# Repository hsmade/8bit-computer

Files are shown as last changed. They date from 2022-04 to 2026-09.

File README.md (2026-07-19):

# My 8-bit computer

This repo describes my homebrew 8-bit computer. 
It is loosely based on the works of  [Ben eater's 6502 computer](https://eater.net/6502), and others.

A build log can be found [here](https://hsmade.github.io/8bit-computer)

## Components
### CPU card
This card contains the CPU and the RAM.

To be built.

* more info [here](CPU/README.md)
* the schematics can be found [here](CPU/kicad/)

### ROM card
This card holds the rom, and exposes a pin header for programming.
I currently do the programming with an Arduino Mega (because I need a lot of IO ports).
The software for programming the eeprom can be found [here](ROM/programmer/README.md)

* more info [here](ROM/README.md).
* the schematic can be found [here](ROM/kicad/).

### Bus display card
This card shows the current contents of the address and data bus, and if the CPU is reading or writing.
I used the trick to alternate between 2 displays, using a timer, from Ben Eater.
This doesn't use the whole flip-flop setup though, as I use just 2 displays per 8 bits (hex).

* more info [here](bus-display/README.md)
* the schematic can be found [here](bus-display/kicad/).

### IO card
This card will interface with the outside world.
The idea is to control a 1602A display, and a serial port.

To be designed and built.

## Requirements
The following software is required to run makefiles:
* cc65
* platformio

## Memory map
http://wilsonminesco.com/6502primer/addr_decoding.html
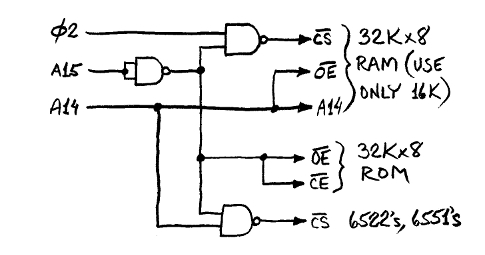
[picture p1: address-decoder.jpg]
address decoder


| start | end  | what | A15 | A14 | A13 | A12 | A11 | A10 | A9 | A8 | A3 | A2 |
|---|---|---|-----|-----|-----|-----|-----|-----|----|----|----|----|
| 0000  | 3FFF | RAM | 0 | 0 | x | x | x | x |  x |  x |  x |  x |
| 4100  | | ACIA 3-1 | 0 | 1 | 0 | 0 | 0 | 0 |  0 |  1 |  0 |  0 |
| 4104  | | ACIA 3-2 | 0 | 1 | 0 | 0 | 0 | 0 |  0 |  1 |  0 |  1 |
| 4108  | | ACIA 3-3 | 0 | 1 | 0 | 0 | 0 | 0 |  0 |  1 |  1 |  0 |
| 410C  | | ACIA 3-4 | 0 | 1 | 0 | 0 | 0 | 0 |  0 |  1 |  1 |  1 |
| 4200  | | ACIA 2-1 | 0 | 1 | 0 | 0 | 0 | 0 |  1 |  0 |  0 |  0 |
| 4204  | | ACIA 2-2 | 0 | 1 | 0 | 0 | 0 | 0 |  1 |  0 |  0 |  1 |
| 4208  | | ACIA 2-3 | 0 | 1 | 0 | 0 | 0 | 0 |  1 |  0 |  1 |  0 |
| 420C  | | ACIA 2-4 | 0 | 1 | 0 | 0 | 0 | 0 |  1 |  0 |  1 |  1 |
| 4400  | 4403 | ACIA 1 | 0 | 1 | 0 | 0 | 0 | 1 |  0 |  0 |  0 |  0 |
| 4800  | 480F | VIA 3 | 0 | 1 | 0 | 0 | 1 | 0 |  0 |  0 |  x |  x |
| 5000  | 500F | VIA 2 | 0 | 1 | 0 | 1 | 0 | 0 |  0 |  0 |  x |  x |
| 6000  | 600F | VIA 1 | 0 | 1 | 1 | 0 | 0 | 0 |  0 |  0 |  x |  x |
| 8000  | FFFF | ROM | 1 | x | x | x | x | x |  x |  x |  x |  x |

`A1` and `A0` select registers inside each ACIA. `A3` through `A0`
select registers inside each VIA. `A7` through `A4` are not decoded in
this memory map.

## Bus

| Use | Port | Port | Use |
|-----|---|---|---|
| VSS | 1 | 40 | VSS |
| X | 2 | 39 | Phi 0 |
| X | 3 | 38 | X |
| +5V | 4 | 37 | +5V |
| A0  | 5 | 36 | X |
| A1  | 6 | 35 | CSb |
| A2  | 7 | 34 | RES |
| A3  | 8 | 33 | NMI |
| A4  | 9 | 32 | IRQ |
| A5  | 10 | 31 | Phi 1 |
| A6  | 11 | 30 | Phi 2 |
| A7  | 12 | 29 | RWb |
| A8  | 13 | 28 | D7 |
| A9  | 14 | 27 | D6 |
| A10 | 15 | 26 | D5 |
| A11 | 16 | 25 | D4 |
| A12 | 17 | 24 | D3 |
| A13 | 18 | 23 | D2 |
| A14 | 19 | 22 | D1 |
| A15 | 20 | 21 | D0 |

## Datasheets
* NAND [74HC00](https://www.mouser.com/catalog/specsheets/nxp_74hc_hct00.pdf)
* CPU [W65C02](https://nl.mouser.com/datasheet/2/436/w65c02s-2572.pdf)
* Power transistor PNP [BD952](https://nl.mouser.com/datasheet/2/54/bd646-1159083.pdf)
* RAM [39SF010A7CPHE](https://nl.mouser.com/datasheet/2/268/20005022C-1832260.pdf)
* 7 segment display [INND-TS40Y*CB](https://nl.mouser.com/datasheet/2/180/INND-TS40_Series_V1.0-1485199.pdf)
* ROM [SST39SF010A](https://nl.mouser.com/datasheet/2/268/20005022C-1832260.pdf)
* ACIA [W65C51](https://nl.mouser.com/datasheet/2/436/WDC_Datasheet%20Update_20141024-1211725.pdf)
* PIO [W65C22](https://nl.mouser.com/datasheet/2/436/w65c22-1197.pdf)

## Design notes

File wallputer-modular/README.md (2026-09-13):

# Modular Wall-Computer

## Setup
|  |  |  |  |
| -- | -- | -- | -- |
|  | [Clock Card](#clock-card) | [CPU Card](#cpu-card) | [Memory Card](#memory-card) |
| [Power Card](#power-card) | [Backplane Card](#backplane-card) | [Backplane Card](#backplane-card) | [Backplane Card](#backplane-card) |
|  | [Bus Display Card](#bus-display-card) | [ACIA Card](#acia-card) | [VIA Card](#via-card) |

## TODO

* finish up BOM using order
* check all footprints
* verify 555 circuits
* verify dual led circuit
* design rp2040 circuit
* verify clock switch circuit
* brightness via bars
* brightness RS-232 leds

## ACIA Card
Used for serial ports.

ACIA card schematic

ACIA card PCB

## Backplane Card

Backplane card schematic

Backplane card PCB

## Bus Display Card

Bus display card schematic

Bus display card PCB

## Clock Card
Generates the clock signal to steer the CPU and other components.

Clock card schematic

Clock card PCB

## CPU Card

CPU card schematic

CPU card PCB

## Memory Card

Memory card schematic

Memory card PCB

## Power Card
Power input and bus signal LEDs.

Power card schematic

Power card PCB

## VIA Card
I/O ports (LCD display, other stuff..)

VIA card schematic

VIA card PCB

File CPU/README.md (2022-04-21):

# CPU module
This module contains the [6502 CPU](https://eater.net/datasheets/w65c02s.pdf) and the 
[RAM](https://www.renesas.com/us/en/document/dst/71256sa-datasheet).
To decode the addresses for the RAM, a `74HC00` NAND is used.
It has a reset button, and LEDs to indicate ongoing interrupts:
- VP (vector pull) - indicates the CPU reading the interrupt vectors
- IRQ - triggers an interrupt
- NMI - triggers a non-maskable interrupt

The LEDs are mostly there for the blinkenlights effect, of course.

For the clock signal, there is a 1MHz oscillator block, a pin header for an external clock signal, 
and a switch button to do single steps. A module with 3 micro switches is used to select the clock input signal.

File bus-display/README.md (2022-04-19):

# Address display
This board helps with debugging in single step mode.
But I mostly created it for the [blinkenlights](https://en.wikipedia.org/wiki/Blinkenlights) factor.
It shows the values on the address, and data busses, and the state of the R/<INS>W</INS> line.

The schematic can be found [here](kicad/).

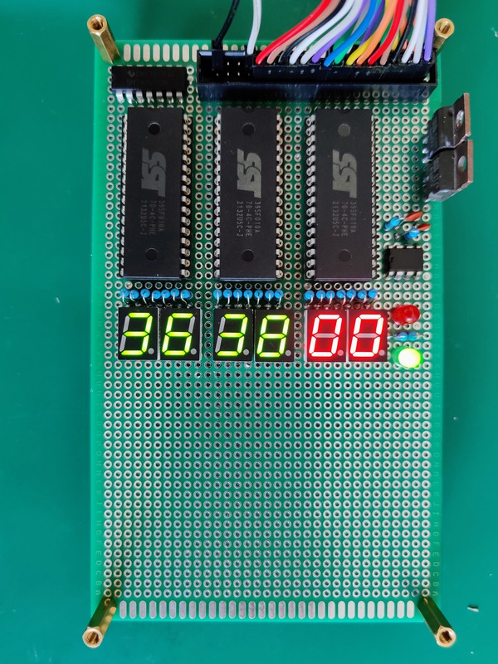
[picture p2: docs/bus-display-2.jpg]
bus display board


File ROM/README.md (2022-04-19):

# ROM / programmer card
This card holds the rom, and exposes a pin header for programming.
I currently do the programming with an Arduino Mega (because I need a lot of IO ports).
The software for programming the eeprom can be found [here](programmer/README.md).
THe Arduino mega board fits right on the bus connector, it just needs a jumper wire for GND,
and jumper wires for `CE`, `WE`, and `OE`.

The schematic can be found [here](kicad/).

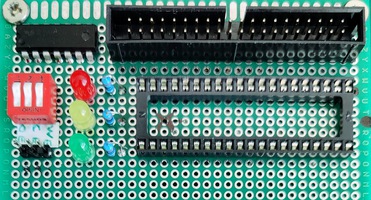
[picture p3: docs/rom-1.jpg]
rom board


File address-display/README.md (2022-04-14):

# Address display
Shows both the address bus and data bus signals as HEX.

## Schema
schema

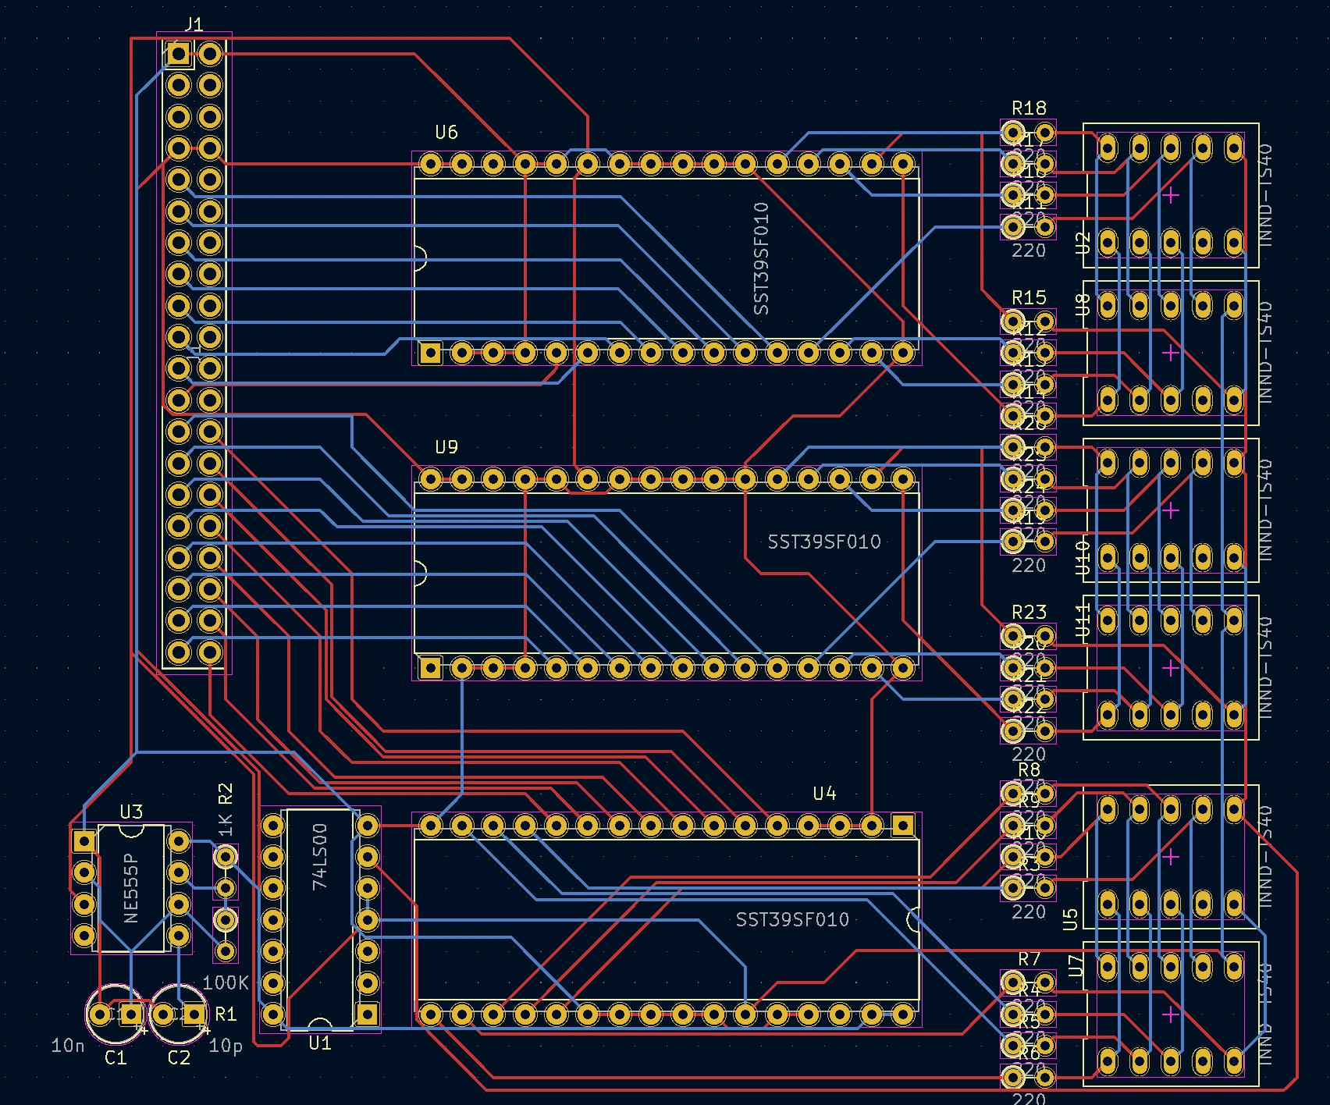
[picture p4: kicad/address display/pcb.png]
pcb


## Bugs / todo
* a NAND is used to invert the clock signal, which delays it a little, causing one of the display to ghost the other
* the PCB is horrible

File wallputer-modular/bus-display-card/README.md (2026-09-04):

# Bus Display Card

This card displays the contents of the address and the data bus in hexadecimals using the 7-segment displays.
The way this works is that each 'address' in the EEPROM has a value that corresponds to the right segments 
on the display. So for example, address 8 has value FE, so it lits up all segments.
The A8 signal is fed a square wave, so half the time we're using 0000-00FF and the 'right' display corresponding
to the right most byte, and the other half we're using FF00-FFFF and the 'left' display.
This way, we can re-use 1 EEPROM for 2 bytes data.

See [display-table.md](display-table.md) for a mapping. Use the script/makefie to generate the EEPROM binary.

Bus display card schematic

Bus display card PCB

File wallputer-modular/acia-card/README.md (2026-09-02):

# ACIA Card

ACIA card schematic

ACIA card PCB

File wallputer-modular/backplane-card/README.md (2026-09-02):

# Backplane Card

Backplane card schematic

Backplane card PCB

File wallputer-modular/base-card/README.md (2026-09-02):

# Base Card

Base card schematic

Base card PCB

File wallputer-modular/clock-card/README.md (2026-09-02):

# Clock Card

Clock card schematic

Clock card PCB

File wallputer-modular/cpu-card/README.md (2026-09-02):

# CPU Card

CPU card schematic

CPU card PCB

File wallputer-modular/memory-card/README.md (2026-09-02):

# Memory Card

Memory card schematic

Memory card PCB

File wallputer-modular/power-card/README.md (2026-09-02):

# Power Card

Power card schematic

Power card PCB

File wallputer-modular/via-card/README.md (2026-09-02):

# VIA Card

VIA card schematic

VIA card PCB

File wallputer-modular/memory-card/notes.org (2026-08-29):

* TODO

** [X] put buffers on RAM/ and ROM/ and a blue led for activation
** [X] lower parts a bit down so the 'address decoder' text gets more space and stuff is in the middle (depends on point above)

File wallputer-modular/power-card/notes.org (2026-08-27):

* TODO

** [X] rewire buffers
** [ ] renumber leds and resistors
** [X] perhaps relocate C's between buffers?
** [?] replace parts around 555 with SMD? = so non-essential parts are all SMD
** [X] find signals for NC's
** [ ] replace resistors around usb-c with SMD
** [X] replace leds to indicate only for:
*** RAM/
*** ROM/
*** ACC/
*** RES/
*** IRQ/
*** NMI/
*** VP/
*** SYNC
** [X] line up connector board with connector placement (26.035 from the top to top pin)

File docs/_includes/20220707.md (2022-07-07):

## [20220707](20220707)
Lots of stuff happened since the last log, but I didn't really spend the time to keep track here.

### Flat cable adventures
I had a hard time getting the rainbow-colored flatcable to fit the connectors.
This caused all kind of issues with the communication between the boards.
In the end, I opted to use an old-school IDE cable.
This of course never turned up, so I bought one from a local computer store.
The cable I bought though, was a more modern IDE cable, with 80 wires and 40 pins.
This also has one pin not connected.

This cable did work a bit better, but still not to satisfaction.
I kept getting random bits flipped over.

### Pin headers
I then decided to use pin headers. These have sockets on top, and long legs on the bottom.
This means, I can stack the boards using the headers.

I desoldered the pin headers I had for the IDE cables, using solder flux.
Of course, I failed to properly clean the ROM board, before putting a new header on.
So when I connected everything together, it shorted out.

I decided to redo the ROM board.
This also gives me the opportunity to add a proper connector for connecting an Arduino Mega, 
for programming the EEPROM.

Here's the schematic for the new ROM board:
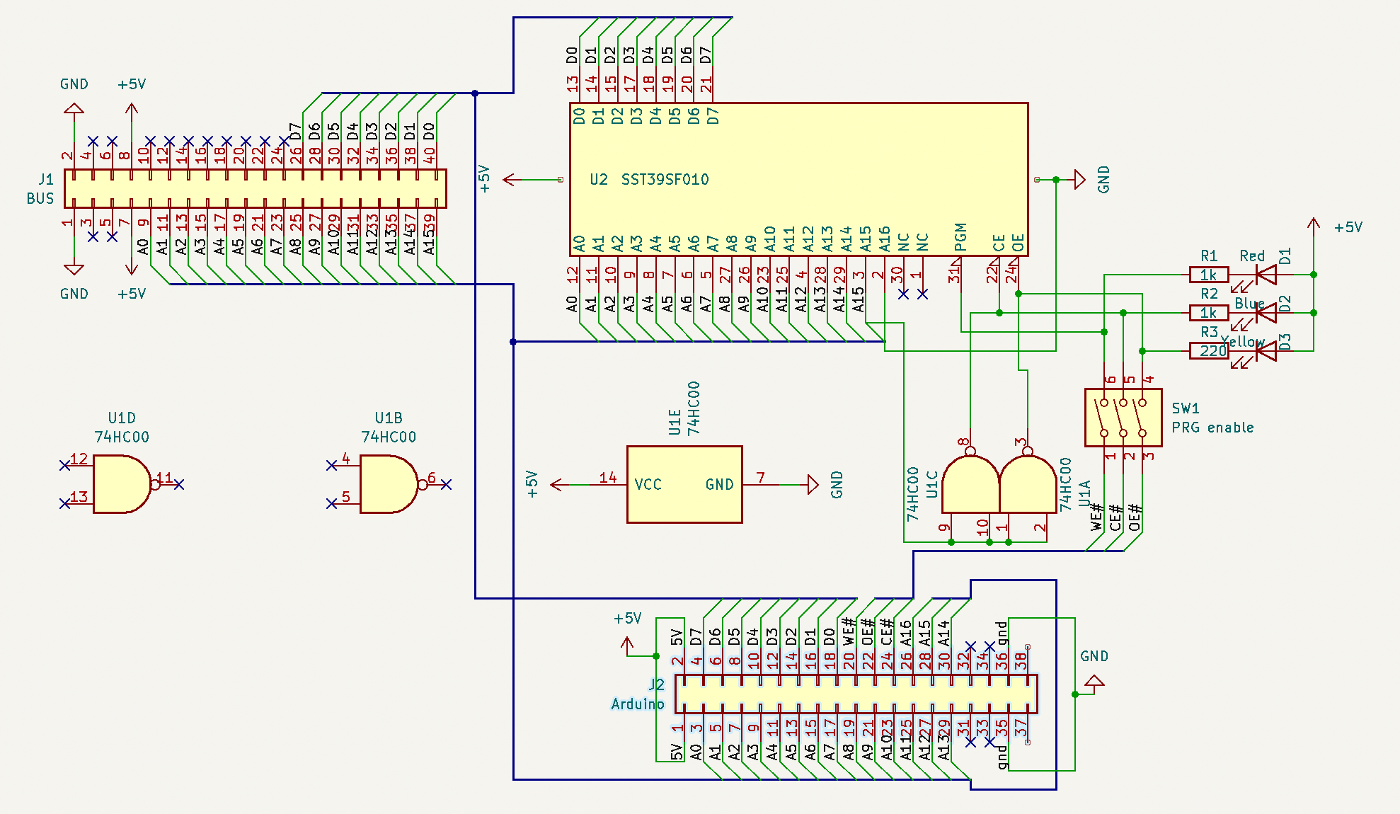
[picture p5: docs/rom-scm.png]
The new ROM board


I'm just finished the control signals on the ROM board, and need to do the I/O.

### Bus display software bug
When you write software, you create bugs.
I found a bug in the bus display board. Instead of `CF`, it will display `FF`.
To fix this, however, I will need to finish my ROM board, annex programmer :)

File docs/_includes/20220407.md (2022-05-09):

## [20220407-ish](20220407)
rom board

The final ROM board.

On the left are the pins for `CE`, `OE`, `WE`, and the switches to attach them to the bus.
The leds show the state of the three signals, from top to bottom.
The `74HC00` has 4 NAND ports, used to control the `CE` and `OE` signals,
so the EEPROM only responds for 0x8000 - 0xFFFF.
The connector on the top is the bus, which connects the board to the CPU.

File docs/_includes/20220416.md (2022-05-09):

## [20220416](20220416)
I soldered the first 2 displays + control logic for the bus-display.
This should allow me to test it and fix errors before I put the rest on the board.
The displays seem to work, the eeprom seems to be connected correctly (I can produce the different outputs).
When I let it display `F0` for example, the segments in the `0` that are different from the `F`, are not fully lit.
When checking the 555 timer output, and the NAND inversion of that output,
I found that the 555 timer doesn't produce a square wave anymore. It did do that on the breadboard,
so I probably either broke something or made a mistake.
Of course I didn't solder an IC socket for the 555, as I didn't have any with 8 pins anymore...
To be investigated...

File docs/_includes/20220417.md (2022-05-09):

## [20220417](20220417)
Refactored this whole repo, to give it more structure.

### Bus display board
After redoing some solder joints, the timer is outputting square waves again.
It does seem the `555` IC can't provide enough current for the led segments of 2 displays.
The `NAND` can, though. I soldered the rest of the segment displays and resistors to the board.
Next I will test if the NAND can provide enough current.
If so, I'll chain two gates together to power the right side displays, instead of the `555` timer.

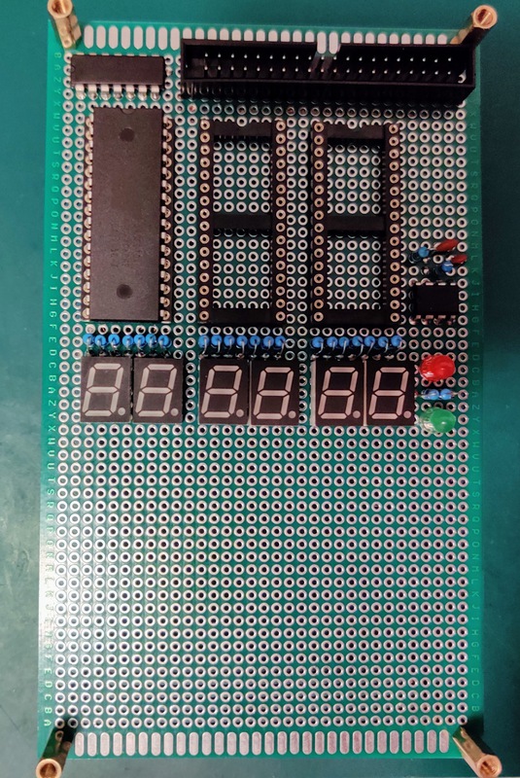
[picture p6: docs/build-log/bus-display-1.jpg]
bus display board


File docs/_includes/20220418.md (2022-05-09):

## [20220418](20220418)
Managed to get the bus display board working!

After some troubleshooting, I figured out that I overlooked something.
Both the `555` timer IC and the `74hc00` NAND IC, can not sink enough current for all the LED segments!
The timer even sinks less than the NAND, as it's more dim.
Since I supply power to the LEDs from the EEPROM data ports,
it ever occurred to me that all that current needs to actually go somewhere.
After going through my (limited) supply of parts, in my junk box, I found some `BD652` PNP power transistors.
I have no clue where I got these and when, but they seem to do the job just fine.
I soldered the rest of the segment displays, resistors and IC sockets,
and tested the board with all segments lit. It looks nice and bright (enough).
A bit of soldering later, the board was finished.

bus display finished

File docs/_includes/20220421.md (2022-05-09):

## [20220421](20220421)
Doing a CPU board mock up.
I want the RAM on the same board as the CPU, or actually, I don't want to waste a whole board for the RAM.

I created a simple schema, so I could use the PCB layout to see what orientation would suite best.
I'm looking for the simples wiring, with few crossings. 
Which is kind of hard with every IC having a different layout for the address and data lines.

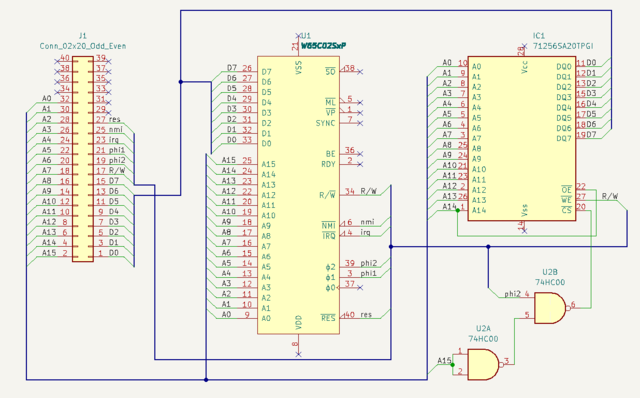
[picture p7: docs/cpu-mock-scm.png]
schema


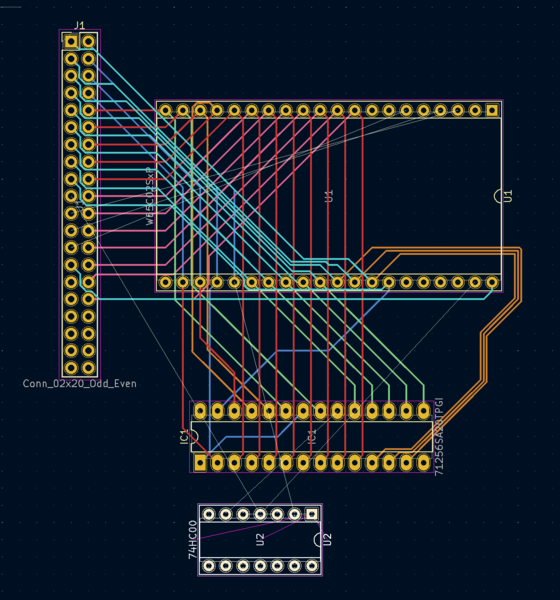
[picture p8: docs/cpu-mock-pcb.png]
pcb


And I want to have 3 different clocks I can select from:
* 1 MHz
* external
* single step

For the single step, I should probably use something like a flip-flop, 
but just a debounced switch seems to do the trick with this CPU.

I also included a reset switch, and some lights for the interrupts:
* VP (Signals that we're inside an interrupt vector)
* IRQ
* NMI

This is what it ended up looking like. 
I'll let this sit for a bit and imagine the wiring process, see if it satisfies me.

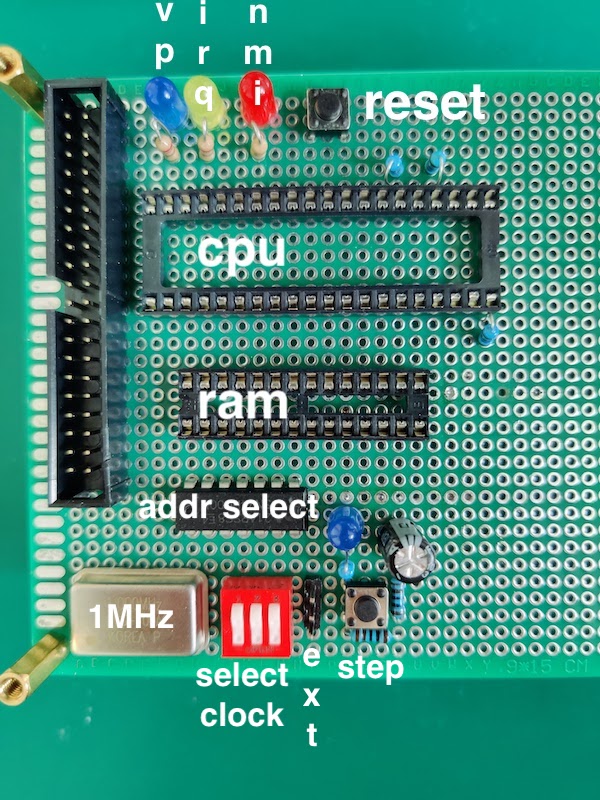
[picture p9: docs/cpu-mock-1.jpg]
mock board


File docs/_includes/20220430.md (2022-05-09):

## [20220430](20220430)
Finished the CPU board.

I didn't add the irq LEDs yet. I'm not sure if I will.
After fixing some mistakes with the wiring, the board seems to work correctly.
However, the flatcable I created has issues. 
This is caused by the wires being a tiny bit too thin, and thus the cable doesn't properly fit the connectors.
I've ordered an old-school IDE cable online, to see if that works out better.

Because of the bad connections on the flatcable, the CPU doesn't get the proper data from the ROM, 
so it's just doing random stuff.

The stack running random stuff

I also ordered better standoffs, as these are too small for the flatcable to fit.
So I needed to put two on top of each other.

After I get the stack of cpu + rom + bus display working correctly, 
I will start on the IO board.
I'm not 100% sure yet what I will use as peripherals. 
Most likely a 1602 Display to start with.
I was also thinking about interfacing with an i2c device, like a temperature sensor.

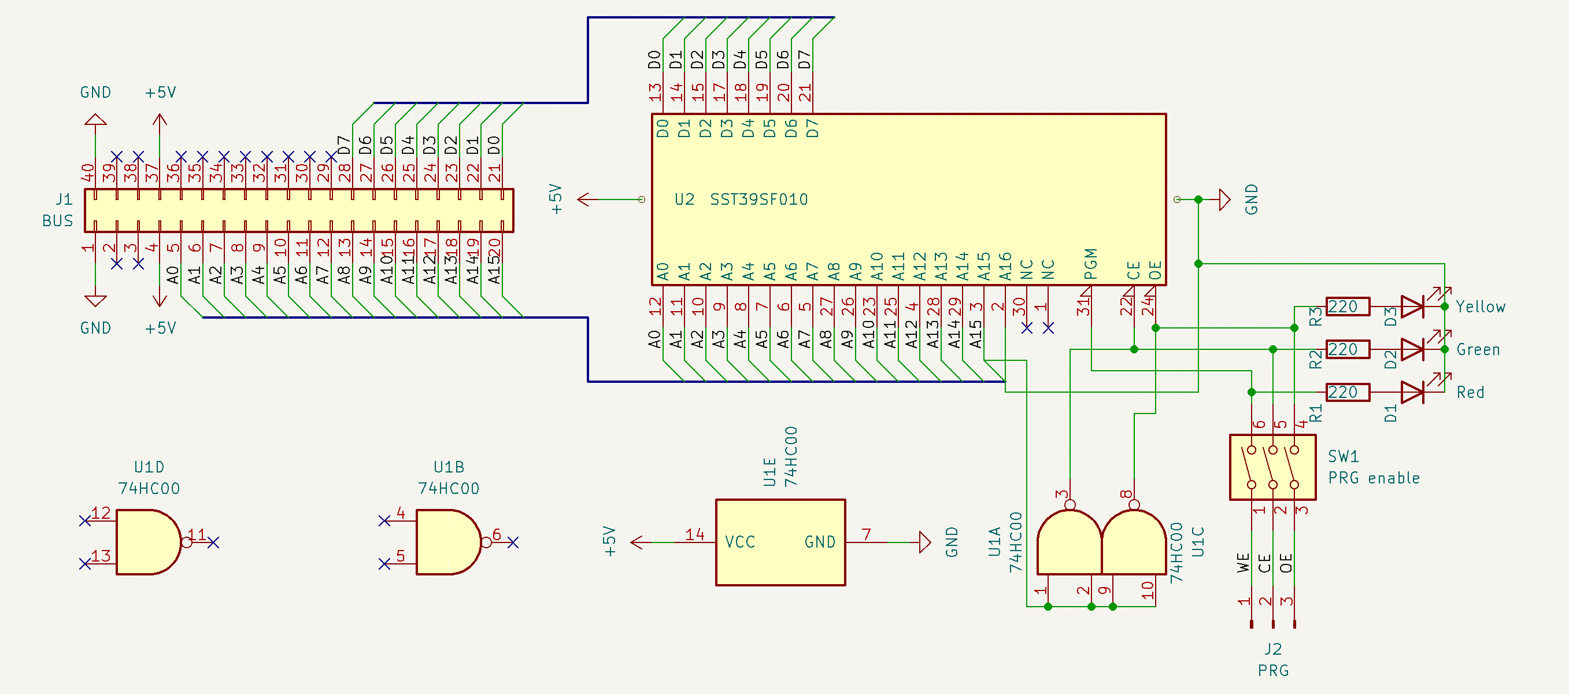
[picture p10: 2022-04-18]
ROM/kicad/rom-board.png

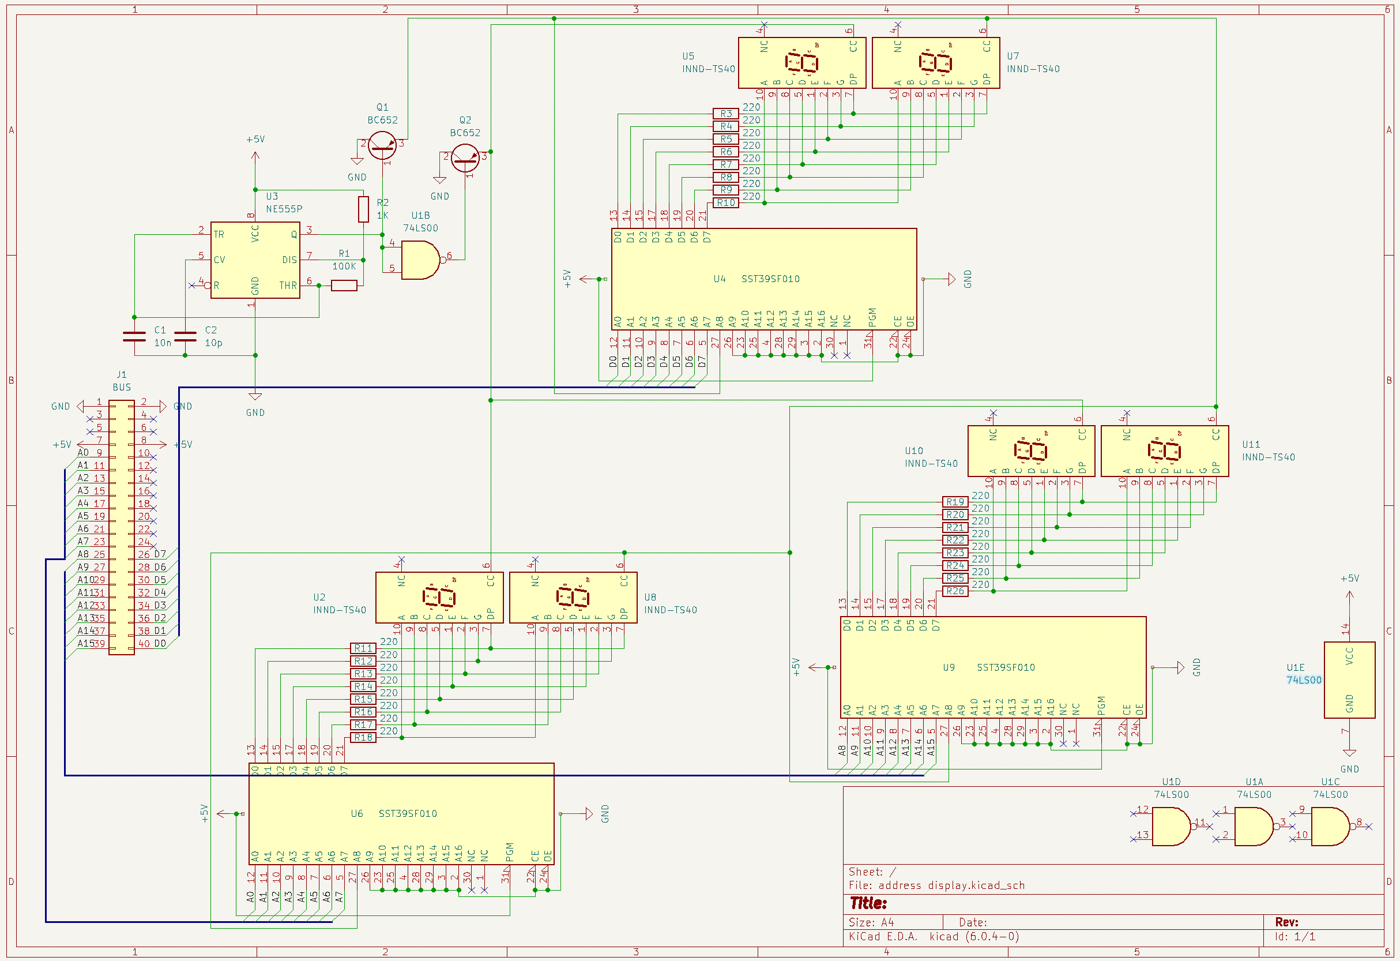
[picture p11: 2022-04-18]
bus-display/kicad/bus display.png

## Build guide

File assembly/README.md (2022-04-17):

# Assembly
This directory contains the files to create a firmware image for the computer.
Currently, [`firmware.s`](firmware.s) contains a test program.

The [`6502.cfg`](6502.cfg) explains `ca65` what the memory map is.

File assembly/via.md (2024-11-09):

```asm
  .org $8000 ; start at $8000

.const VIA1REGB    = $6000  // Input/Output Register "B"
.const VIA1REGA    = $6001  // Input/Output Register "A"
.const VIA1DDRB    = $6002  // Data Direction Register "B"   0 Input 1 Output
.const VIA1DDRA    = $6003  // Data Direction Register "A"   0 Input 1 Output
.const VIA1T1CL    = $6004  // T1 Counter/Low Order Latches
.const VIA1T1CH    = $6005  // T1 High Order Counter
.const VIA1T1LL    = $6006  // T1 Low Order Latches
.const VIA1T1LH    = $6007  // T2 High Order Latches
.const VIA1T2CL    = $6008  // T2 Counter/Low Order Latches
.const VIA1T2CH    = $6009  // T2 High Order Counter
.const VIA1SR      = $600A  // Shift Register
.const VIA1ACR     = $600B  // Auxiliary Control Register
.const VIA1PCR     = $600C  // Peripheral Control Register
.const VIA1IFR     = $600D  // Interrupt Flag Register
.const VIA1IER     = $600E  // Interrupt Enable Register
.const VIA1REGA2   = $600F  // Same as IOREGA w/o Handshake

init:
; set VIA port B to all output
  lda $FF
  sta VIA1DDRB
  
main:
  lda $01 ;; start with LSB set
loop:
  sta VIA1REGB ; write to port B
  rol ; move the bit one left
  jmp loop

nmi:
  jmp main

irq:
  jmp main

.segment  "VECTORS"
  .word nmi   ;$FFFA
  .addr reset ;$FFFC
  .word irq   ;$FFFE

```

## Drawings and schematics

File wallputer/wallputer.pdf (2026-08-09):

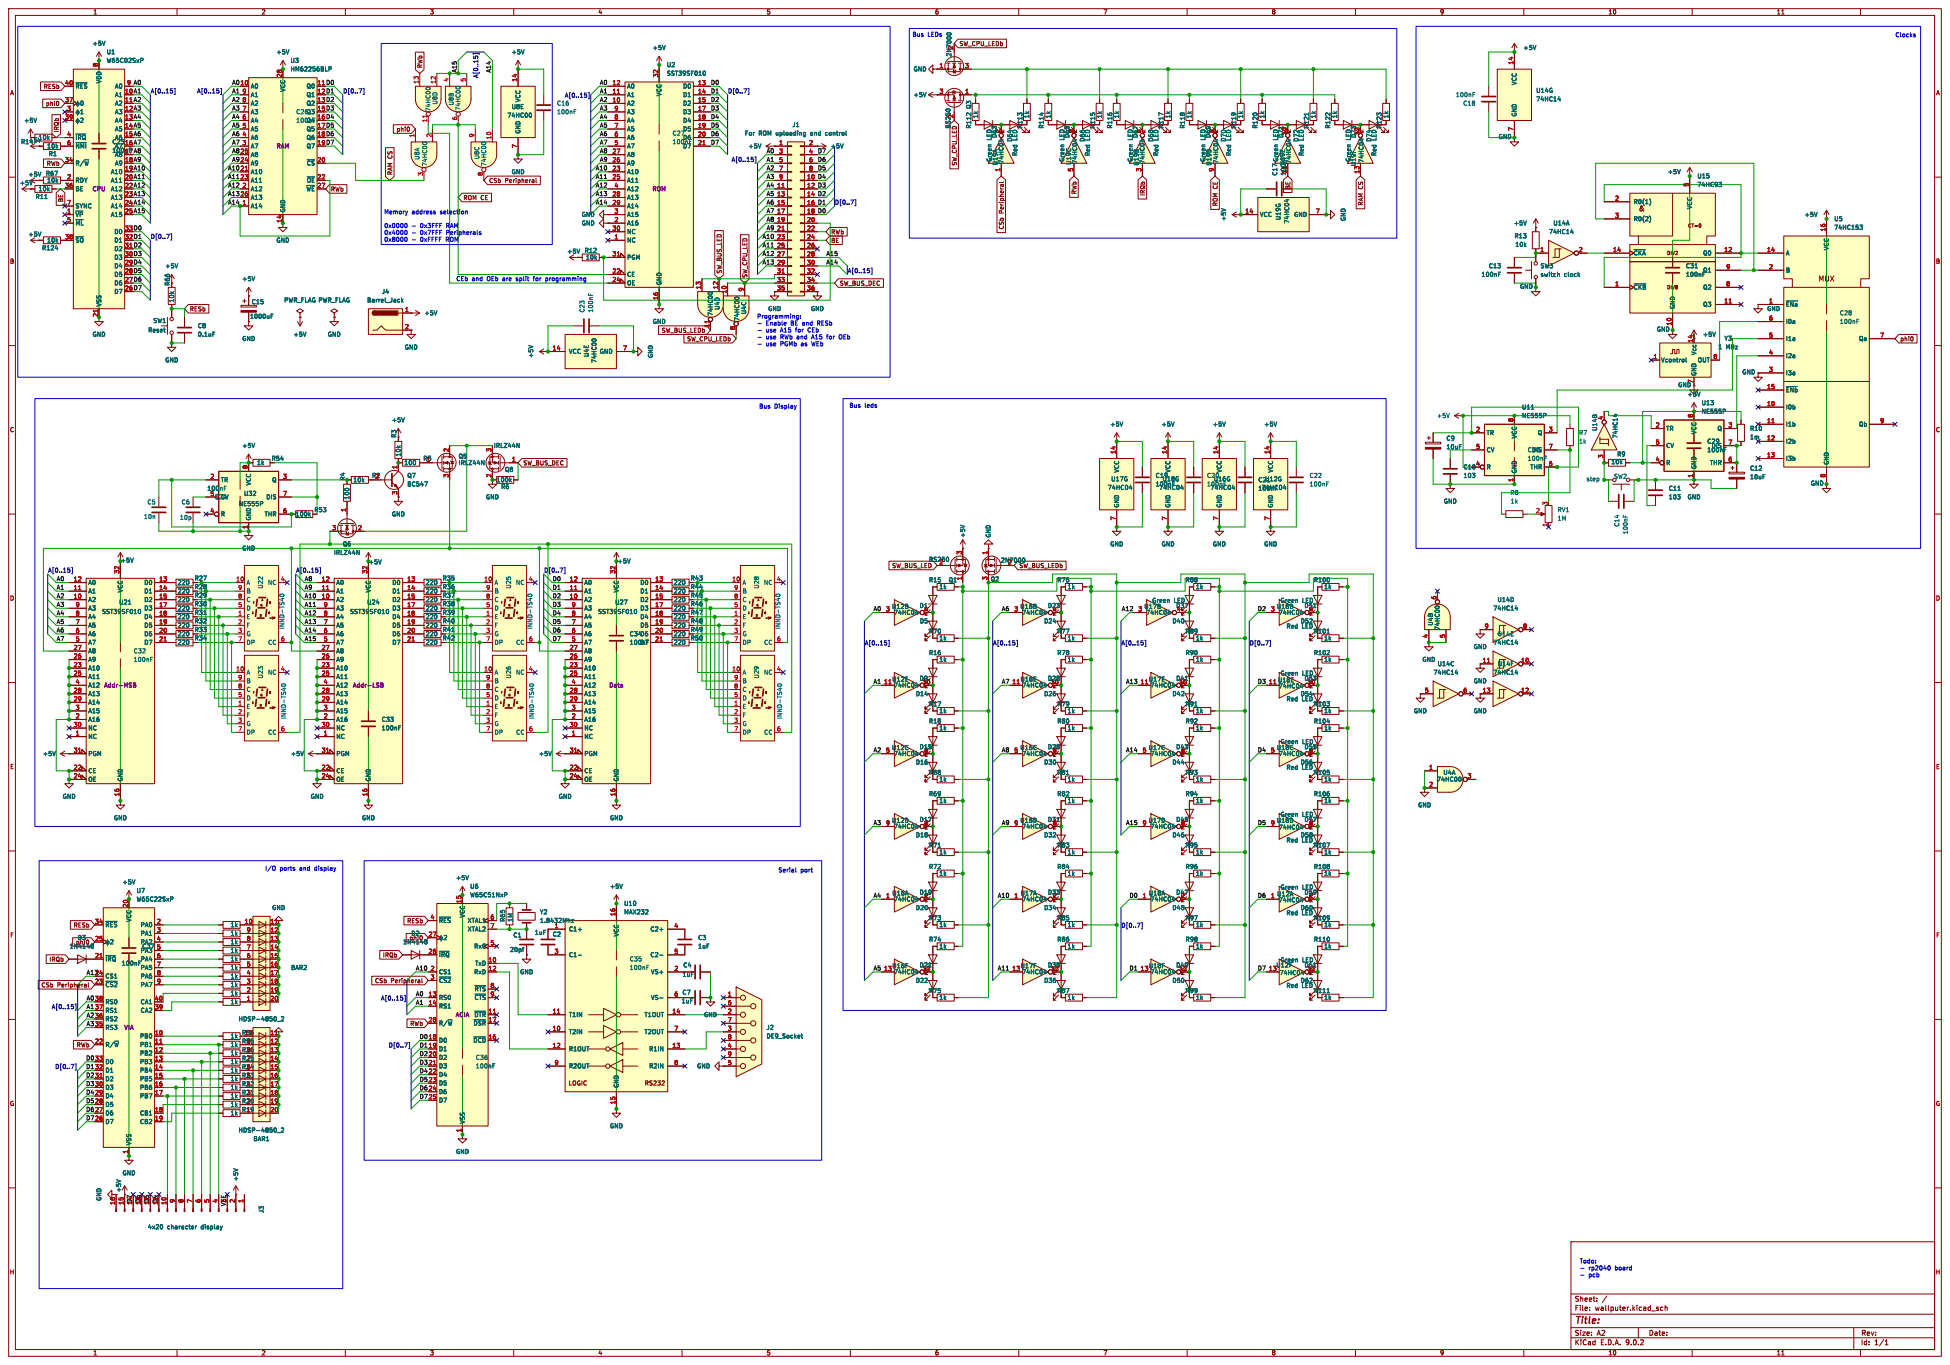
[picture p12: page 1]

Clocks Memory address selection

Bus LEDs Bus Display

7 U2SST39SF010 ROMVCC 32 GND 16 A0 12 A1 11 A2 10 A3 9 A4 8 A5 7 A6 6 A7 5 A8 27 A9 26 A10 23 A11 25 A12 4 A13 28 A14 29 A15 3 A16 2 NC 30 NC 1 PGM 31 CE 22 OE 24 D0 13 D1 14 D2 15 D3 17 D4 18 D5 19 D6 20 D7 21 +5V +5V GND

CEb and OEb are split for programming

Programming: - Enable BE and RESb

- use A15 for CEb
- use RWb and A15 for OEb
- use PGMb as WEb

1 XTAL1 6 XTAL2 7 RxC 5 TxD 10 RxD 12 ~{RTS}8 ~{CTS}9 ~{DTR} 11 ~{DSR} 17 ~{DCD} 16 +5V R41

1 XTAL1 6 XTAL2 7 RxC 5 TxD 10 RxD 12 ~{RTS}8 ~{CTS}9 ~{DTR} 11 ~{DSR} 17 ~{DCD} 16 U6 W65C51NxP

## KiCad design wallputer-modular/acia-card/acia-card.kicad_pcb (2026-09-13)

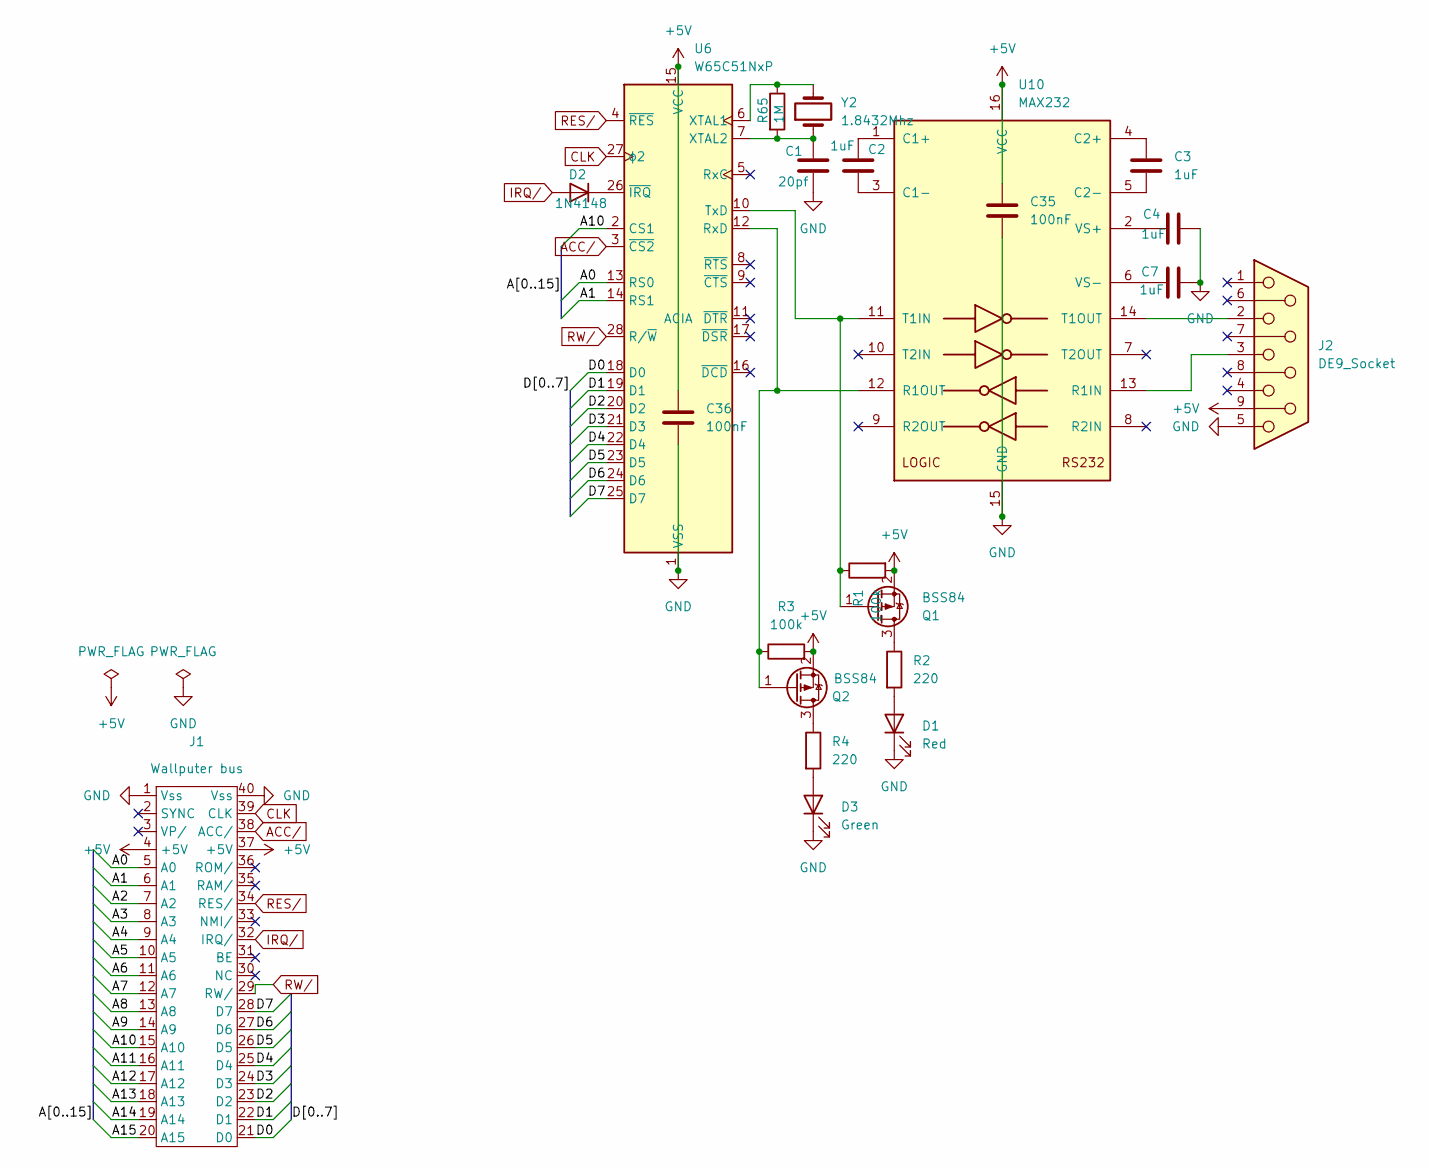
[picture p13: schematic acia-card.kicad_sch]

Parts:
C1: 20pf; C_Disc_D5.0mm_W2.5mm_P5.00mm
C2, C3, C4, C7: 1uF; C_Disc_D5.0mm_W2.5mm_P5.00mm
C35, C36: 100nF; C_Disc_D5.0mm_W2.5mm_P5.00mm
D1: Red; LED_D1.8mm_W3.3mm_H2.4mm
D2: 1N4148; D_DO-35_SOD27_P7.62mm_Horizontal
D3: Green; LED_D1.8mm_W3.3mm_H2.4mm
J1: Wallputer_Bus_Header
J2: DE9_Socket; DSUB-9_Pins_Horizontal_P2.77x2.84mm_EdgePinOffset4.94mm_Hou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
Q1, Q2: BSS84; SOT-23
R1, R3: 100k; R_Axial_DIN0204_L3.6mm_D1.6mm_P2.54mm_Vertical
R2, R4: 220; R_Axial_DIN0204_L3.6mm_D1.6mm_P2.54mm_Vertical
R65: 1M; R_Axial_DIN0204_L3.6mm_D1.6mm_P2.54mm_Vertical
U6: W65C51NxP; DIP-28_W15.24mm
U10: MAX232; DIP-16_W7.62mm_Socket
Y2: 1.8432Mhz; Crystal_HC18-U_Vertical

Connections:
+5V: C35.1, C36.1, J1.4 (+5V), J1.37 (+5V), J2.9, Q1.2 (S), Q2.2 (S), R1.2, R3.2, U6.15 (VCC), U10.16 (VCC)
/A0: J1.5 (A0), U6.13 (RS0)
/A1: J1.6 (A1), U6.14 (RS1)
/A2: J1.7 (A2)
/A3: J1.8 (A3)
/A4: J1.9 (A4)
/A5: J1.10 (A5)
/A6: J1.11 (A6)
/A7: J1.12 (A7)
/A8: J1.13 (A8)
/A9: J1.14 (A9)
/A10: J1.15 (A10), U6.2 (CS1)
/A11: J1.16 (A11)
/A12: J1.17 (A12)
/A13: J1.18 (A13)
/A14: J1.19 (A14)
/A15: J1.20 (A15)
/D0: J1.21 (D0), U6.18 (D0)
/D1: J1.22 (D1), U6.19 (D1)
/D2: J1.23 (D2), U6.20 (D2)
/D3: J1.24 (D3), U6.21 (D3)
/D4: J1.25 (D4), U6.22 (D4)
/D5: J1.26 (D5), U6.23 (D5)
/D6: J1.27 (D6), U6.24 (D6)
/D7: J1.28 (D7), U6.25 (D7)
ACC/: J1.38 (ACC/), U6.3 (~CS2)
CLK: J1.39 (CLK), U6.27 (ϕ2)
GND: C1.2, C4.2, C7.2, C35.2, C36.2, D1.1 (K), D3.1 (K), J1.1 (Vss), J1.40 (Vss), J2.5, U6.1 (VSS), U10.15 (GND)
IRQ/: D2.2 (A), J1.32 (IRQ/)
unnamed: D1.2 (A), R2.2
unnamed: D2.1 (K), U6.26 (~IRQ)
unnamed: D3.2 (A), R4.2
unnamed: Q1.3 (D), R2.1
unnamed: Q1.1 (G), R1.1, U6.10 (TxD), U10.11 (T1IN)
unnamed: Q2.3 (D), R4.1
unnamed: Q2.1 (G), R3.1, U6.12 (RxD), U10.12 (R1OUT)
unnamed: R65.1, U6.6 (XTAL1), Y2.2
unnamed: C1.1, R65.2, U6.7 (XTAL2), Y2.1
unnamed: C2.1, U10.1 (C1+)
unnamed: C2.2, U10.3 (C1-)
unnamed: C3.1, U10.4 (C2+)
unnamed: C3.2, U10.5 (C2-)
unnamed: J2.3, U10.13 (R1IN)
unnamed: J2.2, U10.14 (T1OUT)
unnamed: C4.1, U10.2 (VS+)
unnamed: C7.1, U10.6 (VS-)
RES/: J1.34 (RES/), U6.4 (~RES)
RW/: J1.29 (RW/), U6.28 (R/~W)

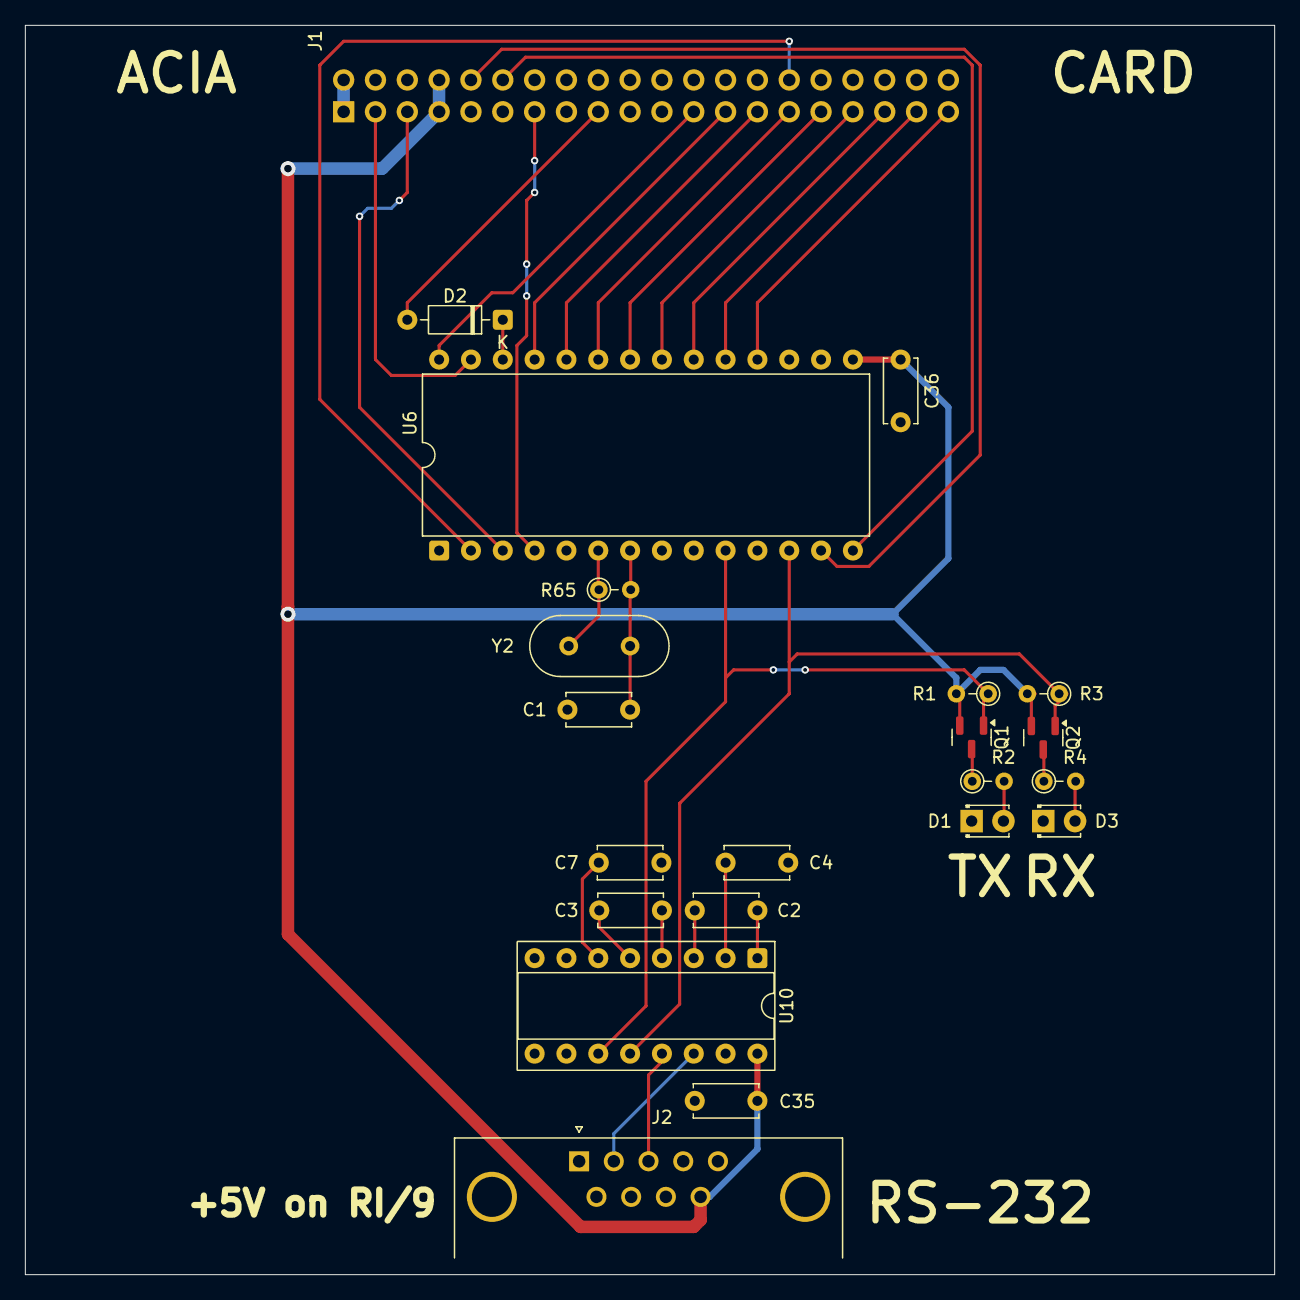
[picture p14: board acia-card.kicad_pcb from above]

Board: 2 copper layers, 99.7 x 99.7 mm, 22 parts (0 on the bottom side), 35 nets.

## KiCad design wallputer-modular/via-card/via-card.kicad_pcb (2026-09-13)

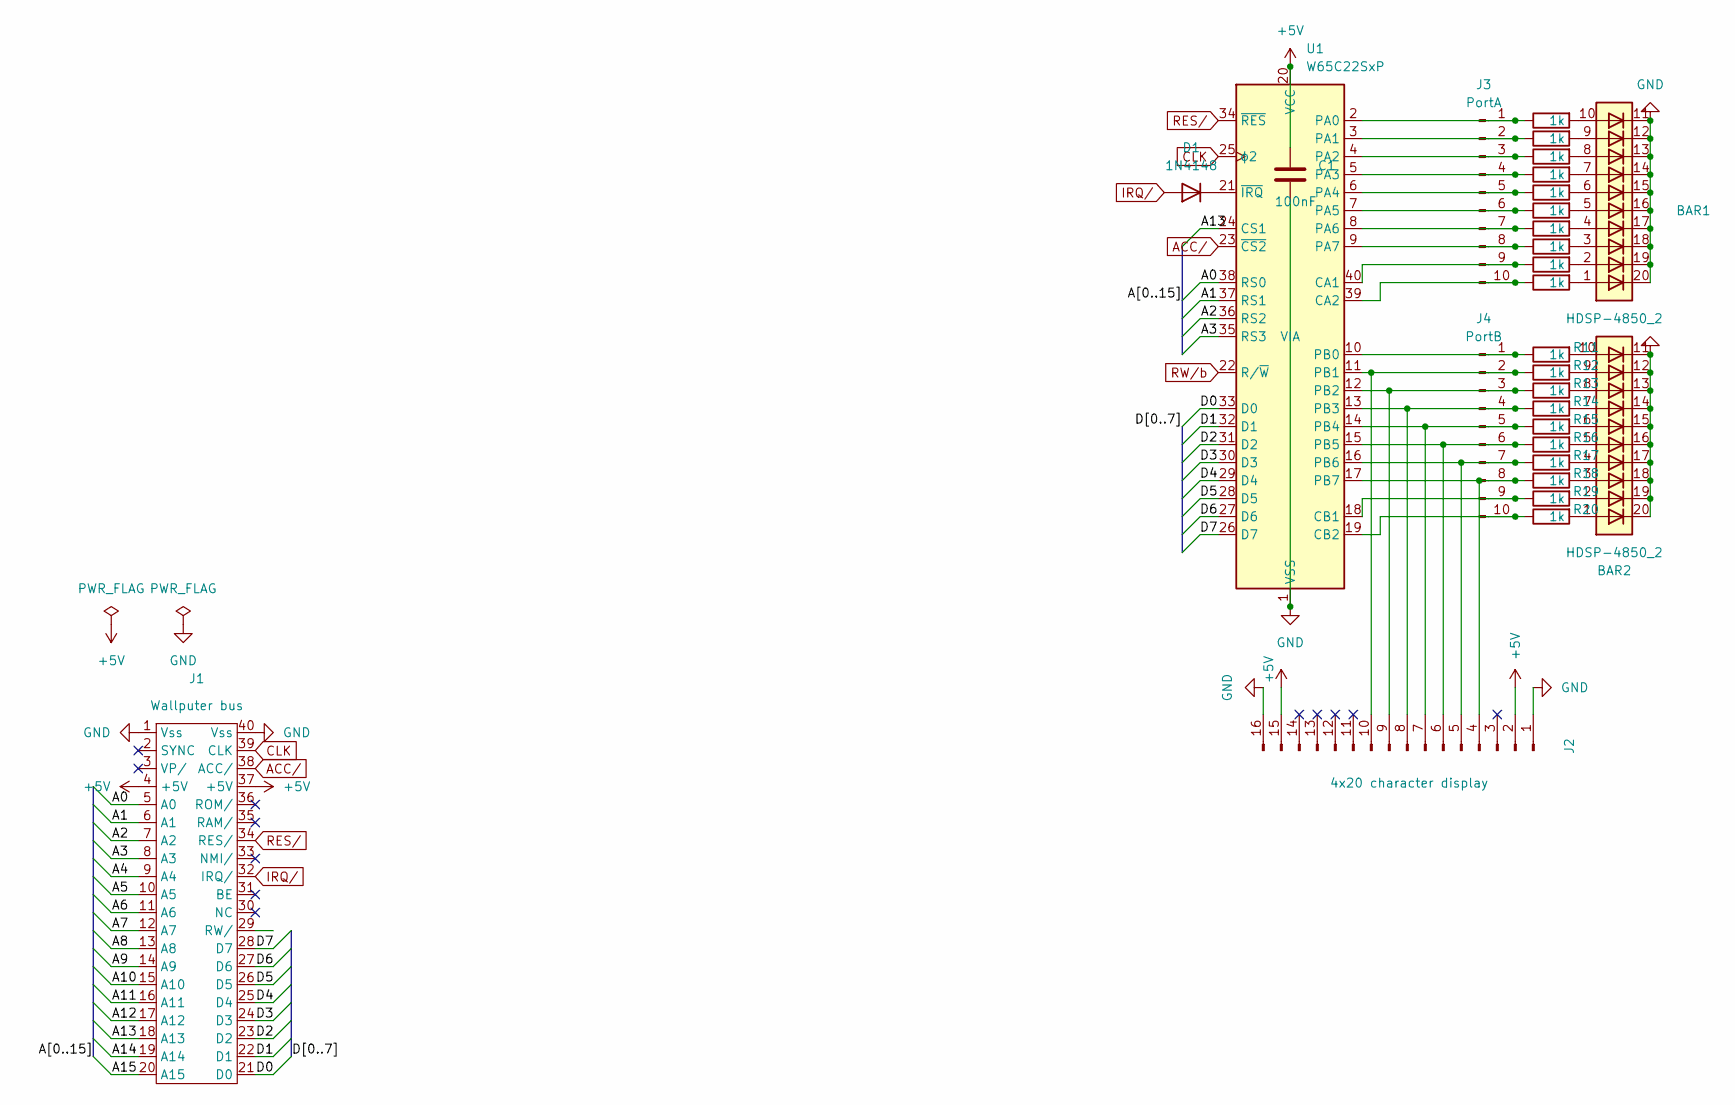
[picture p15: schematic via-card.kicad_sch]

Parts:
BAR1, BAR2: HDSP-4850_2; HDSP-4850
C1: 100nF; C_Disc_D5.0mm_W2.5mm_P5.00mm
D1: 1N4148; D_DO-35_SOD27_P7.62mm_Horizontal
J1: Wallputer_Bus_Header
J2: 4x20 character display; PinHeader_1x16_P2.54mm_Vertical
J3: PortA; PinHeader_1x10_P2.54mm_Vertical
J4: PortB; PinHeader_1x10_P2.54mm_Vertical
R1, R2, R3, R4, R5, R6, R7, R8, R9, R10, R11, R12, R13, R14, R15, R16, R17, R18, R19, R20: 1k; R_Axial_DIN0204_L3.6mm_D1.6mm_P2.54mm_Vertical
U1: W65C22SxP; DIP-40_W15.24mm

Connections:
+5V: C1.1, J1.4 (+5V), J1.37 (+5V), J2.2, J2.15, U1.20 (VCC)
/A0: J1.5 (A0), U1.38 (RS0)
/A1: J1.6 (A1), U1.37 (RS1)
/A2: J1.7 (A2), U1.36 (RS2)
/A3: J1.8 (A3), U1.35 (RS3)
/A4: J1.9 (A4)
/A5: J1.10 (A5)
/A6: J1.11 (A6)
/A7: J1.12 (A7)
/A8: J1.13 (A8)
/A9: J1.14 (A9)
/A10: J1.15 (A10)
/A11: J1.16 (A11)
/A12: J1.17 (A12)
/A13: J1.18 (A13), U1.24 (CS1)
/A14: J1.19 (A14)
/A15: J1.20 (A15)
/D0: J1.21 (D0), U1.33 (D0)
/D1: J1.22 (D1), U1.32 (D1)
/D2: J1.23 (D2), U1.31 (D2)
/D3: J1.24 (D3), U1.30 (D3)
/D4: J1.25 (D4), U1.29 (D4)
/D5: J1.26 (D5), U1.28 (D5)
/D6: J1.27 (D6), U1.27 (D6)
/D7: J1.28 (D7), U1.26 (D7)
ACC/: J1.38 (ACC/), U1.23 (~CS2)
CLK: J1.39 (CLK), U1.25 (ϕ2)
GND: BAR1.11 (K), BAR1.12 (K), BAR1.13 (K), BAR1.14 (K), BAR1.15 (K), BAR1.16 (K), BAR1.17 (K), BAR1.18 (K), BAR1.19 (K), BAR1.20 (K), BAR2.11 (K), BAR2.12 (K), BAR2.13 (K), BAR2.14 (K), BAR2.15 (K), BAR2.16 (K), BAR2.17 (K), BAR2.18 (K), BAR2.19 (K), BAR2.20 (K), C1.2, J1.1 (Vss), J1.40 (Vss), J2.1, J2.16, U1.1 (VSS)
IRQ/: D1.2 (A), J1.32 (IRQ/)
unnamed: BAR1.1 (A), R10.2
unnamed: BAR1.2 (A), R9.2
unnamed: BAR1.3 (A), R8.2
unnamed: BAR1.4 (A), R7.2
unnamed: BAR1.5 (A), R6.2
unnamed: BAR1.6 (A), R5.2
unnamed: BAR1.7 (A), R4.2
unnamed: BAR1.8 (A), R3.2
unnamed: BAR1.9 (A), R2.2
unnamed: BAR1.10 (A), R1.2
unnamed: BAR2.1 (A), R20.2
unnamed: BAR2.2 (A), R19.2
unnamed: BAR2.3 (A), R18.2
unnamed: BAR2.4 (A), R17.2
unnamed: BAR2.5 (A), R16.2
unnamed: BAR2.6 (A), R15.2
unnamed: BAR2.7 (A), R14.2
unnamed: BAR2.8 (A), R13.2
unnamed: BAR2.9 (A), R12.2
unnamed: BAR2.10 (A), R11.2
unnamed: D1.1 (K), U1.21 (~IRQ)
unnamed: J2.4, J4.8, R18.1, U1.17 (PB7)
unnamed: J2.5, J4.7, R17.1, U1.16 (PB6)
unnamed: J2.6, J4.6, R16.1, U1.15 (PB5)
unnamed: J2.7, J4.5, R15.1, U1.14 (PB4)
unnamed: J2.8, J4.4, R14.1, U1.13 (PB3)
unnamed: J2.9, J4.3, R13.1, U1.12 (PB2)
unnamed: J2.10, J4.2, R12.1, U1.11 (PB1)
unnamed: J3.1, R1.1, U1.2 (PA0)
unnamed: J3.2, R2.1, U1.3 (PA1)
unnamed: J3.3, R3.1, U1.4 (PA2)
unnamed: J3.4, R4.1, U1.5 (PA3)
unnamed: J3.5, R5.1, U1.6 (PA4)
unnamed: J3.6, R6.1, U1.7 (PA5)
unnamed: J3.7, R7.1, U1.8 (PA6)
unnamed: J3.8, R8.1, U1.9 (PA7)
unnamed: J3.9, R9.1, U1.40 (CA1)
unnamed: J3.10, R10.1, U1.39 (CA2)
unnamed: J4.1, R11.1, U1.10 (PB0)
unnamed: J4.9, R19.1, U1.18 (CB1)
unnamed: J4.10, R20.1, U1.19 (CB2)
RES/: J1.34 (RES/), U1.34 (~RES)
RW/b: U1.22 (R/~W)

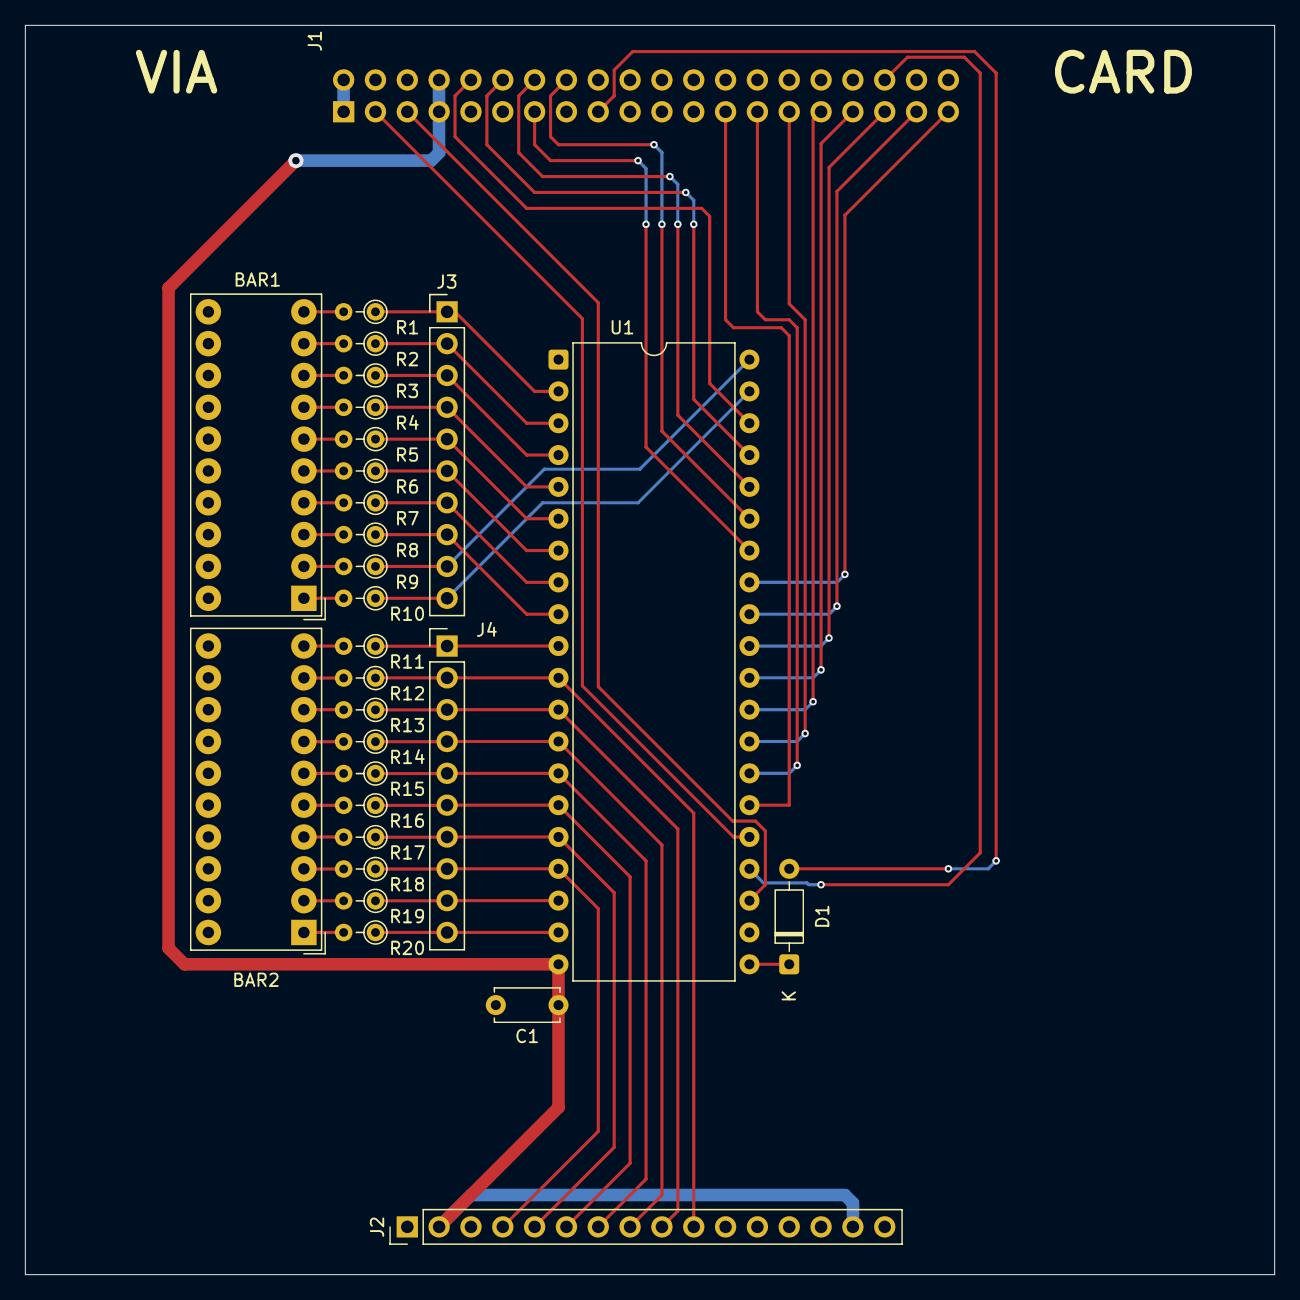
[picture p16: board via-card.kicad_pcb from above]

Board: 2 copper layers, 99.7 x 99.7 mm, 29 parts (0 on the bottom side), 60 nets.

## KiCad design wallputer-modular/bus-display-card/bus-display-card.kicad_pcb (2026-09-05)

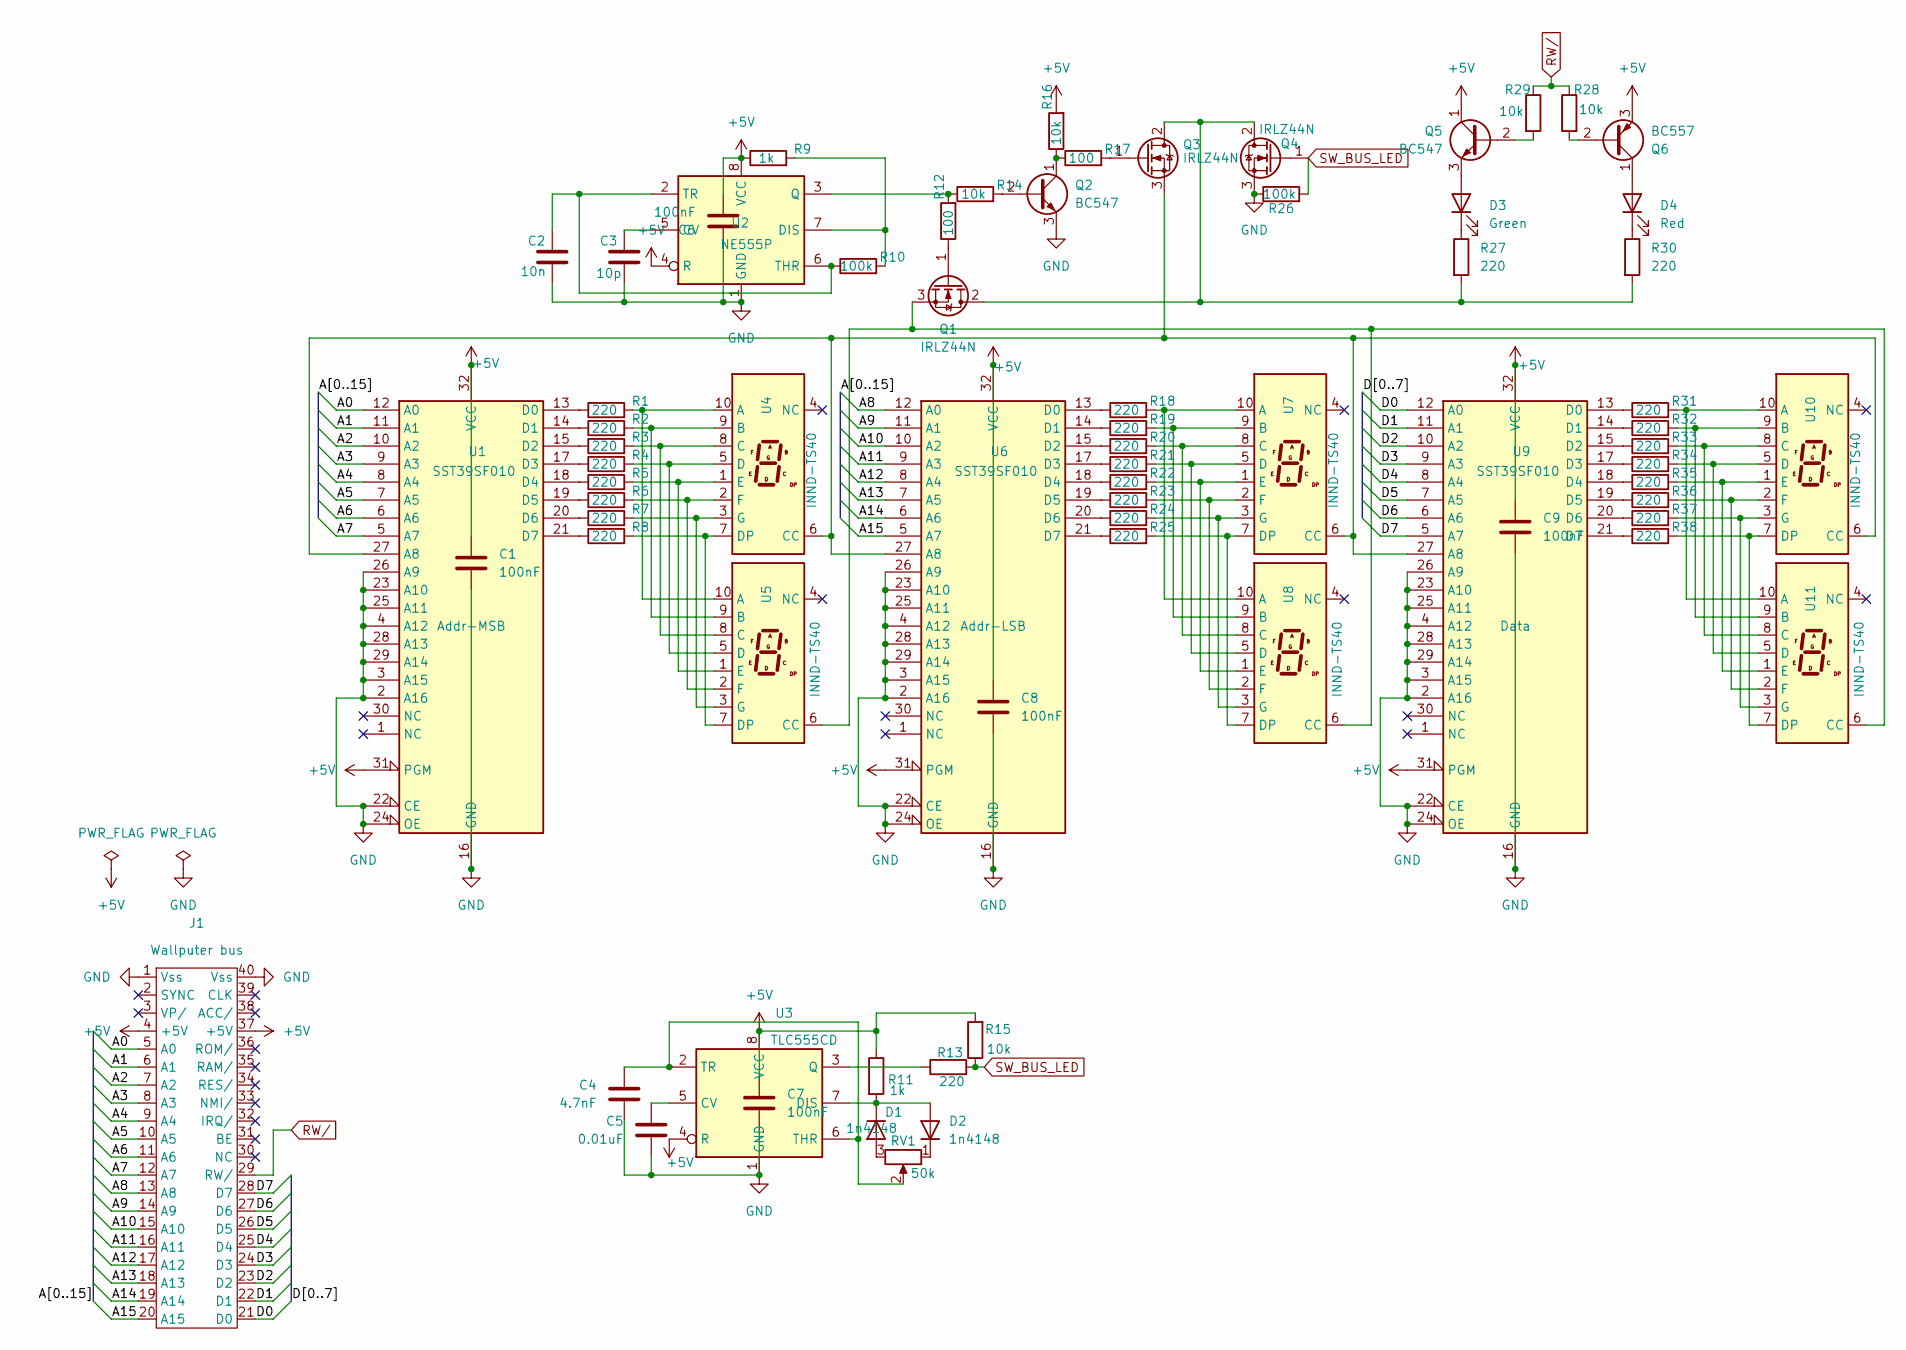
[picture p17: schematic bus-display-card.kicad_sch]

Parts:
C1, C6, C7, C8, C9: 100nF; C_Disc_D5.0mm_W2.5mm_P5.00mm
C2: 10n; C_Disc_D5.0mm_W2.5mm_P5.00mm
C3: 10p; C_Disc_D5.0mm_W2.5mm_P5.00mm
C4: 4.7nF; C_Disc_D5.0mm_W2.5mm_P5.00mm
C5: 0.01uF; C_Disc_D5.0mm_W2.5mm_P5.00mm
D1, D2: 1n4148; D_DO-35_SOD27_P7.62mm_Horizontal
D3: Green; LED_D3.0mm
D4: Red; LED_D3.0mm
J1: Wallputer_Bus_Header
Q1, Q3, Q4: IRLZ44N; TO-220-3_Vertical
Q2, Q5: BC547; TO-92_Inline
Q6: BC557; TO-92_Inline
R1, R2, R3, R4, R5, R6, R7, R8, R13, R18, R19, R20, R21, R22, R23, R24, R25, R27, R30, R31, R32, R33, R34, R35, R36, R37, R38: 220; R_Axial_DIN0204_L3.6mm_D1.6mm_P2.54mm_Vertical
R9, R11: 1k; R_Axial_DIN0204_L3.6mm_D1.6mm_P2.54mm_Vertical
R10, R26: 100k; R_Axial_DIN0204_L3.6mm_D1.6mm_P2.54mm_Vertical
R12, R17: 100; R_Axial_DIN0204_L3.6mm_D1.6mm_P2.54mm_Vertical
R14, R15, R16, R28, R29: 10k; R_Axial_DIN0204_L3.6mm_D1.6mm_P2.54mm_Vertical
RV1: 50k; Potentiometer_Alpha_RD901F-40-00D_Single_Vertical
U1, U6, U9: SST39SF010; DIP-32_W15.24mm_Socket
U2: NE555P; DIP-8_W7.62mm
U3: TLC555CD; DIP-8_W7.62mm
U4, U5, U7, U8, U10, U11: INND-TS40

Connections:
+5V: C1.1, C6.2, C7.1, C8.1, C9.1, J1.4 (+5V), J1.37 (+5V), Q5.1 (C), Q6.3 (E), R9.1, R11.1, R15.2, R16.2, U1.31 (PGM), U1.32 (VCC), U2.4 (R), U2.8 (VCC), U3.4 (R), U3.8 (VCC), U6.31 (PGM), U6.32 (VCC), U9.31 (PGM), U9.32 (VCC)
/A0: J1.5 (A0), U1.12 (A0)
/A1: J1.6 (A1), U1.11 (A1)
/A2: J1.7 (A2), U1.10 (A2)
/A3: J1.8 (A3), U1.9 (A3)
/A4: J1.9 (A4), U1.8 (A4)
/A5: J1.10 (A5), U1.7 (A5)
/A6: J1.11 (A6), U1.6 (A6)
/A7: J1.12 (A7), U1.5 (A7)
/A8: J1.13 (A8), U6.12 (A0)
/A9: J1.14 (A9), U6.11 (A1)
/A10: J1.15 (A10), U6.10 (A2)
/A11: J1.16 (A11), U6.9 (A3)
/A12: J1.17 (A12), U6.8 (A4)
/A13: J1.18 (A13), U6.7 (A5)
/A14: J1.19 (A14), U6.6 (A6)
/A15: J1.20 (A15), U6.5 (A7)
/D0: J1.21 (D0), U9.12 (A0)
/D1: J1.22 (D1), U9.11 (A1)
/D2: J1.23 (D2), U9.10 (A2)
/D3: J1.24 (D3), U9.9 (A3)
/D4: J1.25 (D4), U9.8 (A4)
/D5: J1.26 (D5), U9.7 (A5)
/D6: J1.27 (D6), U9.6 (A6)
/D7: J1.28 (D7), U9.5 (A7)
GND: C1.2, C2.2, C3.2, C4.2, C5.1, C6.1, C7.2, C8.2, C9.2, J1.1 (Vss), J1.40 (Vss), Q2.3 (E), Q4.3 (S), R26.1, U1.2 (A16), U1.3 (A15), U1.4 (A12), U1.16 (GND), U1.22 (CE), U1.23 (A10), U1.24 (OE), U1.25 (A11), U1.26 (A9), U1.28 (A13), U1.29 (A14), U2.1 (GND), U3.1 (GND), U6.2 (A16), U6.3 (A15), U6.4 (A12), U6.16 (GND), U6.22 (CE), U6.23 (A10), U6.24 (OE), U6.25 (A11), U6.26 (A9), U6.28 (A13), U6.29 (A14), U9.2 (A16), U9.3 (A15), U9.4 (A12), U9.16 (GND), U9.22 (CE), U9.23 (A10), U9.24 (OE), U9.25 (A11), U9.26 (A9), U9.28 (A13), U9.29 (A14)
unnamed: D1.2 (A), RV1.3
unnamed: D1.1 (K), D2.2 (A), R11.2, U3.7 (DIS)
unnamed: D2.1 (K), RV1.1
unnamed: D3.2 (A), Q5.3 (E)
unnamed: D3.1 (K), R27.1
unnamed: D4.2 (A), Q6.1 (C)
unnamed: D4.1 (K), R30.1
unnamed: Q1.2 (D), Q3.2 (D), Q4.2 (D), R27.2, R30.2
unnamed: Q1.1 (G), R12.1
unnamed: Q1.3 (S), U5.6 (CC), U8.6 (CC), U11.6 (CC)
unnamed: Q2.2 (B), R14.2
unnamed: Q2.1 (C), R16.1, R17.1
unnamed: Q3.1 (G), R17.2
unnamed: Q3.3 (S), U1.27 (A8), U4.6 (CC), U6.27 (A8), U7.6 (CC), U9.27 (A8), U10.6 (CC)
unnamed: Q5.2 (B), R28.2
unnamed: Q6.2 (B), R29.2
unnamed: R1.1, U1.13 (D0)
unnamed: R2.1, U1.14 (D1)
unnamed: R3.1, U1.15 (D2)
unnamed: R4.1, U1.17 (D3)
unnamed: R5.1, U1.18 (D4)
unnamed: R6.1, U1.19 (D5)
unnamed: R7.1, U1.20 (D6)
unnamed: R8.1, U1.21 (D7)
unnamed: C3.1, U2.5 (CV)
unnamed: R9.2, R10.2, U2.7 (DIS)
unnamed: R12.2, R14.1, U2.3 (Q)
unnamed: C2.1, R10.1, U2.2 (TR), U2.6 (THR)
unnamed: C5.2, U3.5 (CV)
unnamed: R13.1, U3.3 (Q)
unnamed: C4.1, RV1.2, U3.2 (TR), U3.6 (THR)
unnamed: R1.2, U4.10 (A), U5.10 (A)
unnamed: R2.2, U4.9 (B), U5.9 (B)
unnamed: R3.2, U4.8 (C), U5.8 (C)
unnamed: R4.2, U4.5 (D), U5.5 (D)
unnamed: R8.2, U4.7 (DP), U5.7 (DP)
unnamed: R5.2, U4.1 (E), U5.1 (E)
unnamed: R6.2, U4.2 (F), U5.2 (F)
unnamed: R7.2, U4.3 (G), U5.3 (G)
unnamed: R18.1, U6.13 (D0)
unnamed: R19.1, U6.14 (D1)
unnamed: R20.1, U6.15 (D2)
unnamed: R21.1, U6.17 (D3)
unnamed: R22.1, U6.18 (D4)
unnamed: R23.1, U6.19 (D5)
unnamed: R24.1, U6.20 (D6)
unnamed: R25.1, U6.21 (D7)
unnamed: R18.2, U7.10 (A), U8.10 (A)
unnamed: R19.2, U7.9 (B), U8.9 (B)
unnamed: R20.2, U7.8 (C), U8.8 (C)
unnamed: R21.2, U7.5 (D), U8.5 (D)
unnamed: R25.2, U7.7 (DP), U8.7 (DP)
unnamed: R22.2, U7.1 (E), U8.1 (E)
unnamed: R23.2, U7.2 (F), U8.2 (F)
unnamed: R24.2, U7.3 (G), U8.3 (G)
unnamed: R31.1, U9.13 (D0)
unnamed: R32.1, U9.14 (D1)
unnamed: R33.1, U9.15 (D2)
unnamed: R34.1, U9.17 (D3)
unnamed: R35.1, U9.18 (D4)
unnamed: R36.1, U9.19 (D5)
unnamed: R37.1, U9.20 (D6)
unnamed: R38.1, U9.21 (D7)
unnamed: R31.2, U10.10 (A), U11.10 (A)
unnamed: R32.2, U10.9 (B), U11.9 (B)
unnamed: R33.2, U10.8 (C), U11.8 (C)
unnamed: R34.2, U10.5 (D), U11.5 (D)
unnamed: R38.2, U10.7 (DP), U11.7 (DP)
unnamed: R35.2, U10.1 (E), U11.1 (E)
unnamed: R36.2, U10.2 (F), U11.2 (F)
unnamed: R37.2, U10.3 (G), U11.3 (G)
RW/: J1.29 (RW/), R28.1, R29.1
SW_BUS_LED: Q4.1 (G), R13.2, R15.1, R26.2

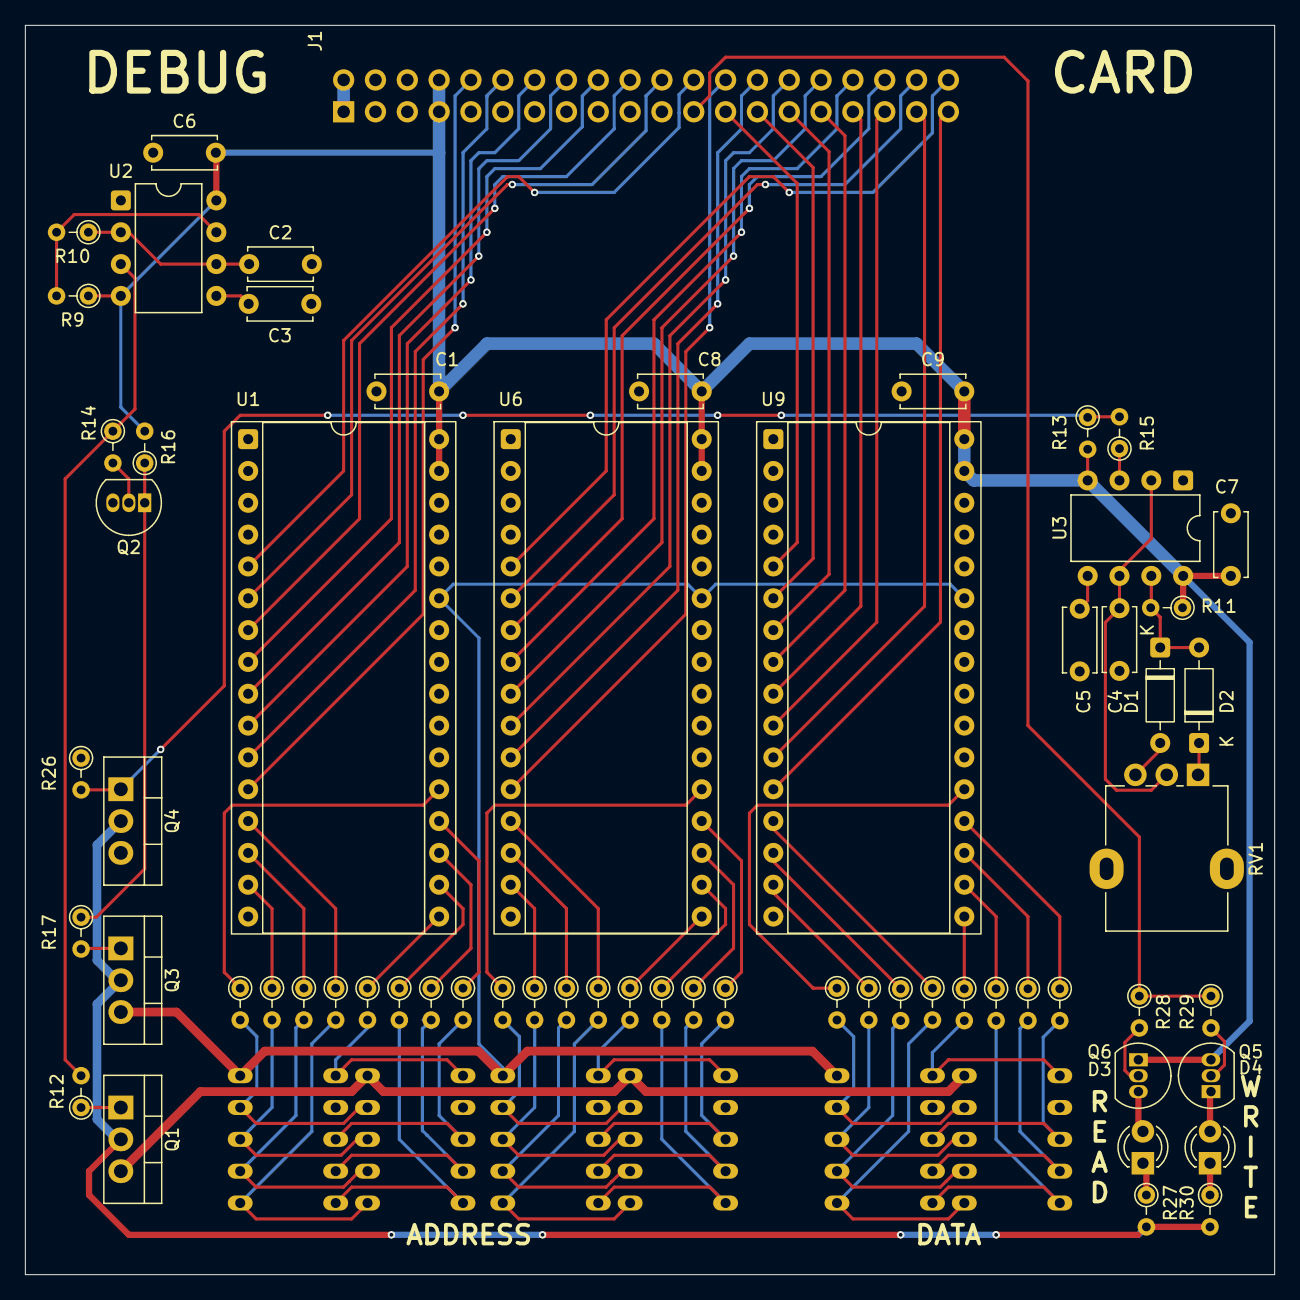
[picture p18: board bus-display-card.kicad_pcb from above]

Board: 2 copper layers, 99.7 x 99.7 mm, 70 parts (0 on the bottom side), 99 nets.

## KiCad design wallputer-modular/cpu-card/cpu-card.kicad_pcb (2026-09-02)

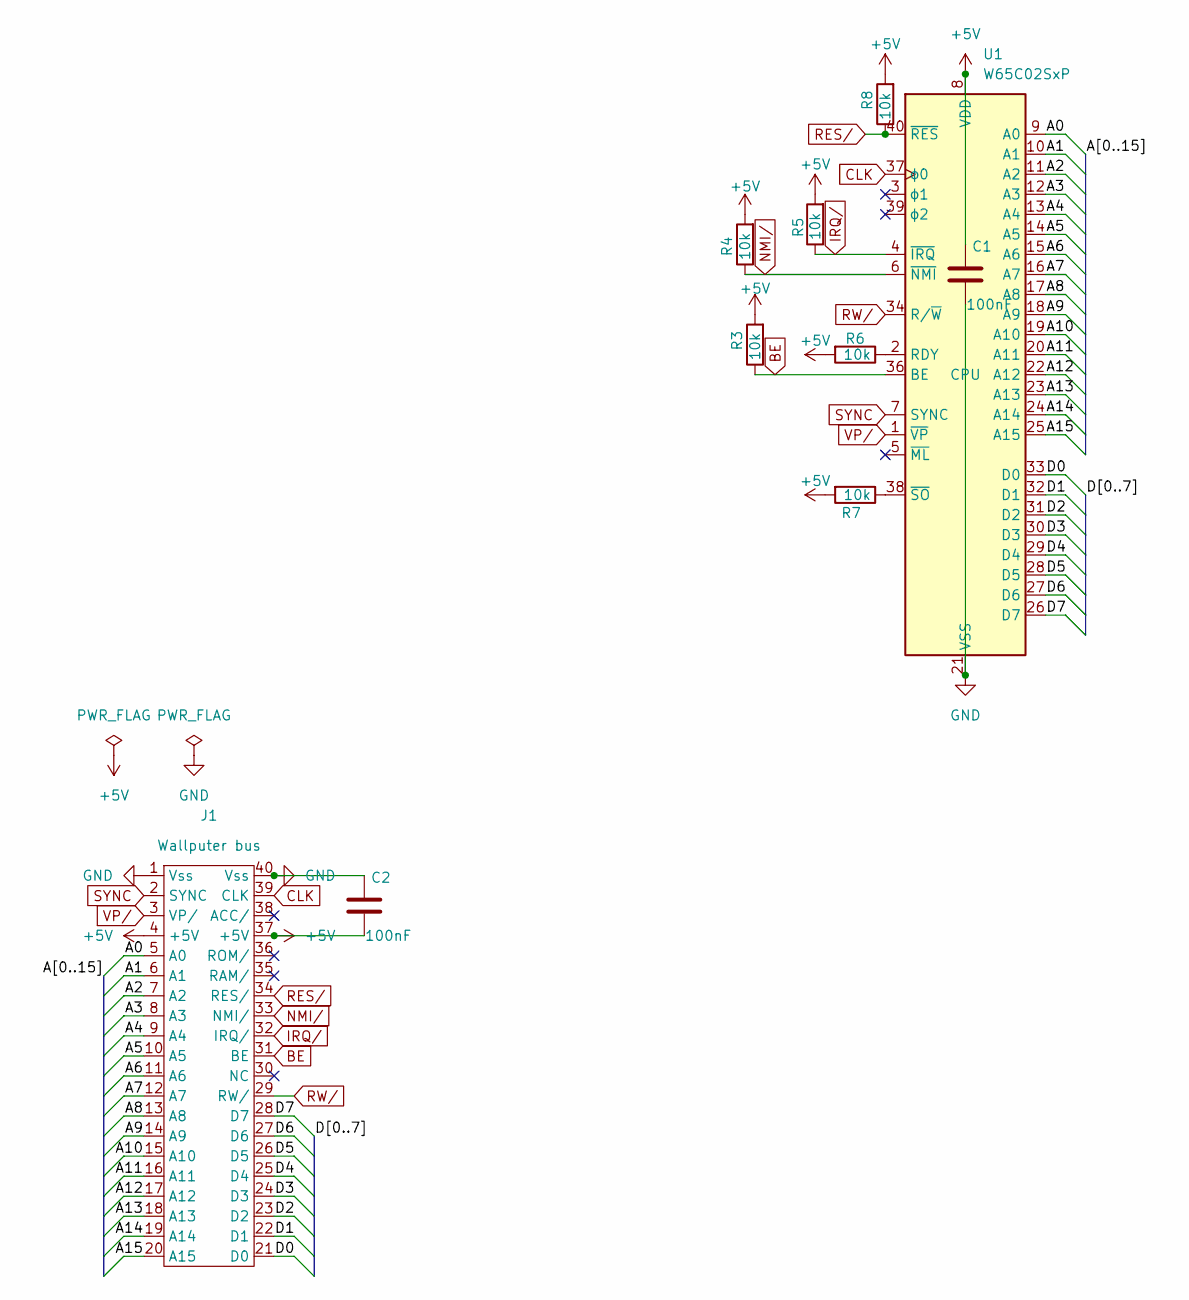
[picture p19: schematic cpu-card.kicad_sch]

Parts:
C1, C2: 100nF; C_Disc_D5.0mm_W2.5mm_P5.00mm
J1: Wallputer_Bus_Header
R3, R4, R5, R6, R7, R8: 10k; R_Axial_DIN0204_L3.6mm_D1.6mm_P2.54mm_Vertical
U1: W65C02SxP; DIP-40_W15.24mm_Socket

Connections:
+5V: C1.1, C2.2, J1.4 (+5V), J1.37 (+5V), R3.2, R4.2, R5.2, R6.2, R7.2, R8.2, U1.8 (VDD)
/A0: J1.5 (A0), U1.9 (A0)
/A1: J1.6 (A1), U1.10 (A1)
/A2: J1.7 (A2), U1.11 (A2)
/A3: J1.8 (A3), U1.12 (A3)
/A4: J1.9 (A4), U1.13 (A4)
/A5: J1.10 (A5), U1.14 (A5)
/A6: J1.11 (A6), U1.15 (A6)
/A7: J1.12 (A7), U1.16 (A7)
/A8: J1.13 (A8), U1.17 (A8)
/A9: J1.14 (A9), U1.18 (A9)
/A10: J1.15 (A10), U1.19 (A10)
/A11: J1.16 (A11), U1.20 (A11)
/A12: J1.17 (A12), U1.22 (A12)
/A13: J1.18 (A13), U1.23 (A13)
/A14: J1.19 (A14), U1.24 (A14)
/A15: J1.20 (A15), U1.25 (A15)
/D0: J1.21 (D0), U1.33 (D0)
/D1: J1.22 (D1), U1.32 (D1)
/D2: J1.23 (D2), U1.31 (D2)
/D3: J1.24 (D3), U1.30 (D3)
/D4: J1.25 (D4), U1.29 (D4)
/D5: J1.26 (D5), U1.28 (D5)
/D6: J1.27 (D6), U1.27 (D6)
/D7: J1.28 (D7), U1.26 (D7)
BE: J1.31 (BE), R3.1, U1.36 (BE)
CLK: J1.39 (CLK), U1.37 (ϕ0)
GND: C1.2, C2.1, J1.1 (Vss), J1.40 (Vss), U1.21 (VSS)
IRQ/: J1.32 (IRQ/), R5.1, U1.4 (~IRQ)
NMI/: J1.33 (NMI/), R4.1, U1.6 (~NMI)
unnamed: R6.1, U1.2 (RDY)
unnamed: R7.1, U1.38 (~SO)
RES/: J1.34 (RES/), R8.1, U1.40 (~RES)
RW/: J1.29 (RW/), U1.34 (R/~W)
SYNC: J1.2 (SYNC), U1.7 (SYNC)
VP/: J1.3 (VP/), U1.1 (~VP)

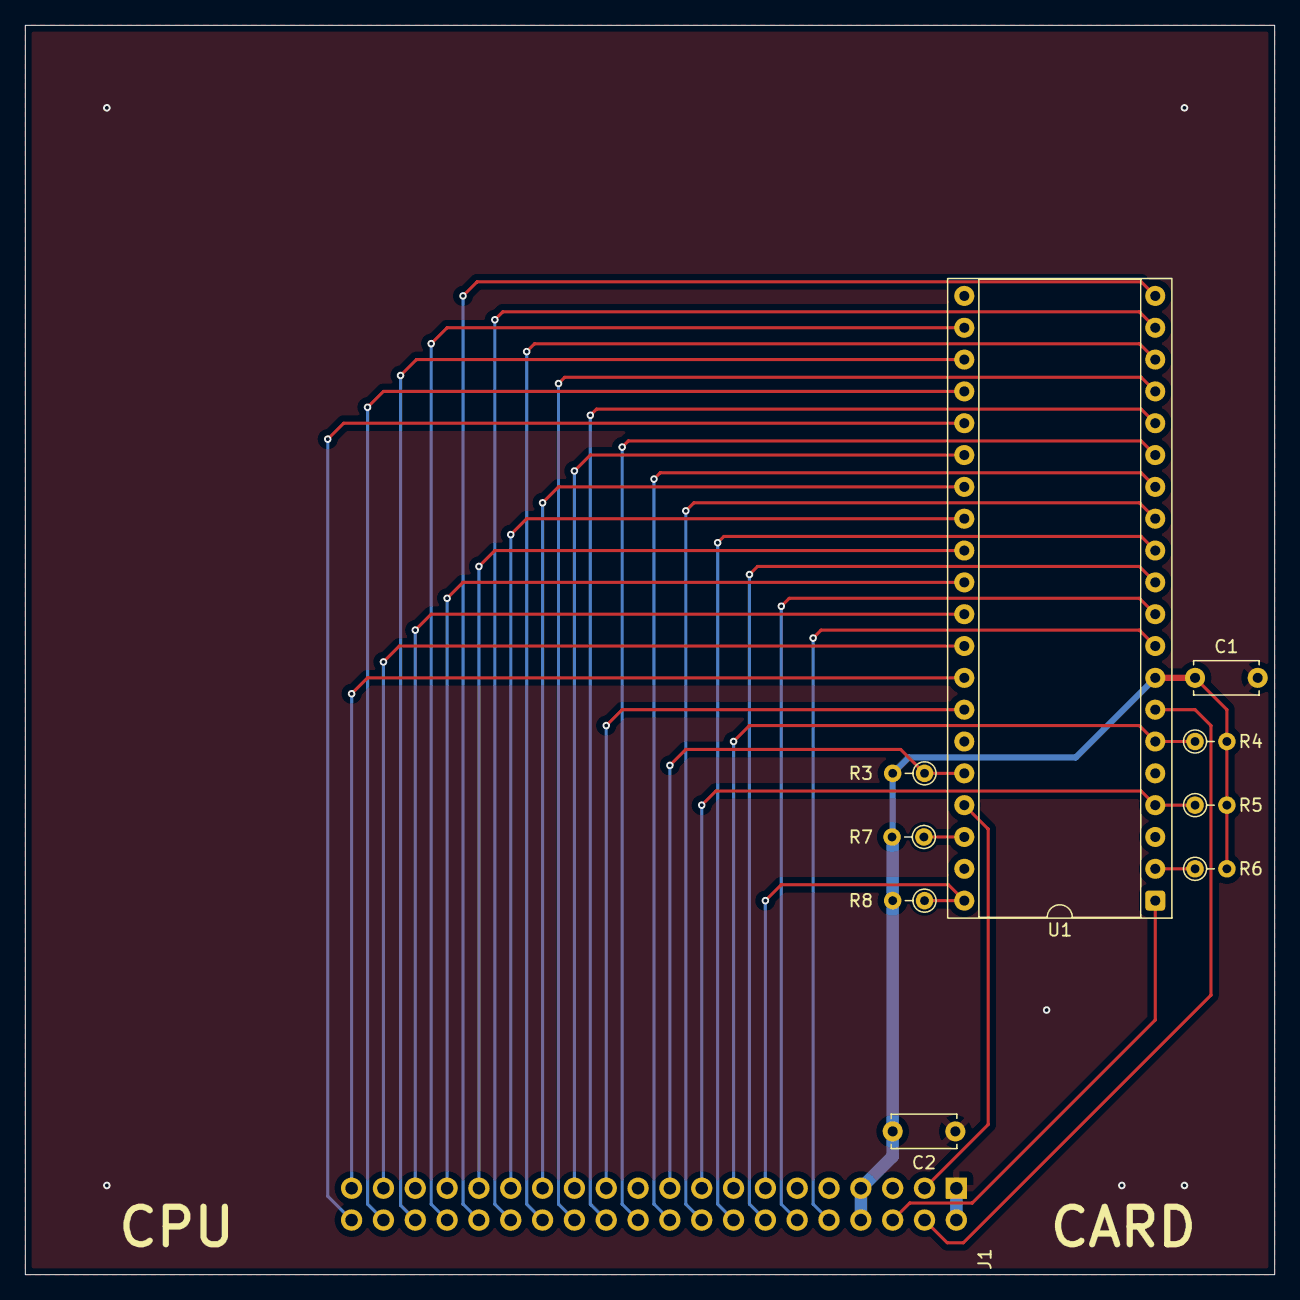
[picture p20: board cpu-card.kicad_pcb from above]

Board: 2 copper layers, 99.7 x 99.7 mm, 10 parts (0 on the bottom side), 36 nets.

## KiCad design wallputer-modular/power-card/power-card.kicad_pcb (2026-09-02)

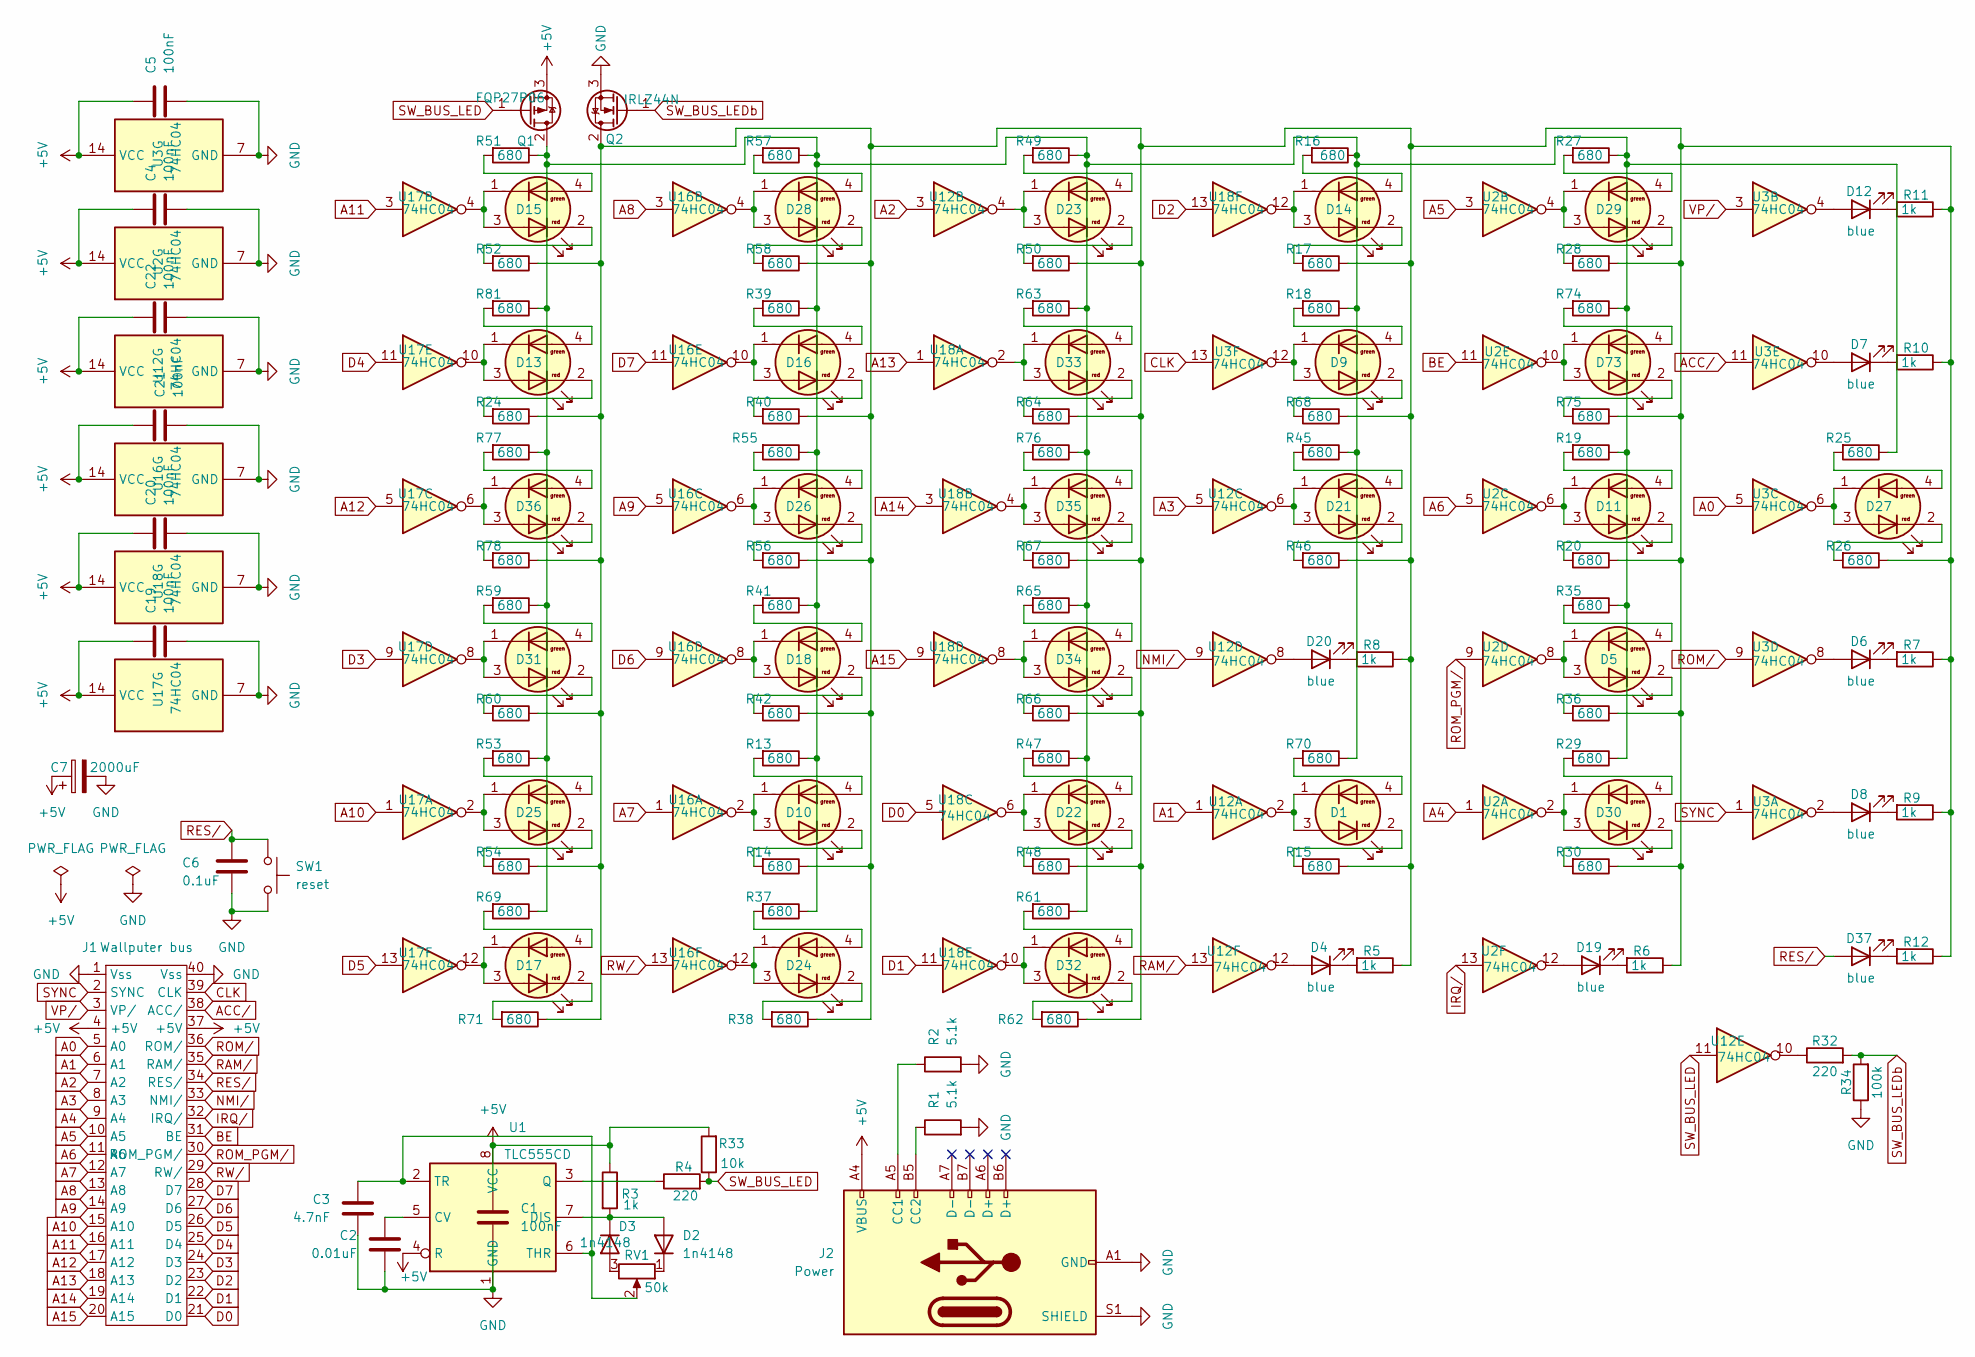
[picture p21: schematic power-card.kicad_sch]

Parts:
C1, C4, C5, C19, C20, C21, C22: 100nF; C_Disc_D5.0mm_W2.5mm_P5.00mm
C2: 0.01uF; C_Disc_D5.0mm_W2.5mm_P5.00mm
C3: 4.7nF; C_Disc_D5.0mm_W2.5mm_P5.00mm
C6: 0.1uF; C_Disc_D5.0mm_W2.5mm_P5.00mm
C7: 2000uF; CP_Radial_D18.0mm_P7.50mm
D1, D5, D9, D10, D11, D13, D14, D15, D16, D17, D18, D21, D22, D23, D24, D25, D26, D27, D28, D29, D30, D31, D32, D33, D34, D35, D36, D73: Wallputer_Dual_LED
D2, D3: 1n4148; D_DO-35_SOD27_P7.62mm_Horizontal
D4, D6, D7, D8, D12, D19, D20, D37: blue; LED_1206_3216Metric
J1: Wallputer_Bus_*
J2: Power; USB_C_Receptacle_HRO_TYPE-C-31-M-12
Q1: FQP27P06; TO-220-3_Vertical
Q2: IRLZ44N; TO-220-3_Vertical
R1, R2: 5.1k; R_Axial_DIN0204_L3.6mm_D1.6mm_P2.54mm_Vertical
R3: 1k; R_Axial_DIN0204_L3.6mm_D1.6mm_P2.54mm_Vertical
R4, R32: 220; R_Axial_DIN0204_L3.6mm_D1.6mm_P2.54mm_Vertical
R5, R6, R7, R8, R9, R10, R11, R12: 1k; R_0603_1608Metric
R13, R14, R15, R16, R17, R18, R19, R20, R24, R25, R26, R27, R28, R29, R30, R35, R36, R37, R38, R39, R40, R41, R42, R45, R46, R47, R48, R49, R50, R51, R52, R53, R54, R55, R56, R57, R58, R59, R60, R61, R62, R63, R64, R65, R66, R67, R68, R69, R70, R71, R74, R75, R76, R77, R78, R81: 680; R_0603_1608Metric
R33: 10k; R_Axial_DIN0204_L3.6mm_D1.6mm_P2.54mm_Vertical
R34: 100k; R_Axial_DIN0204_L3.6mm_D1.6mm_P2.54mm_Vertical
RV1: 50k; Potentiometer_Alpha_RD901F-40-00D_Single_Vertical
SW1: reset; SW_PUSH_6mm_H4.3mm
U1: TLC555CD; DIP-8_W7.62mm
U2, U3, U12, U16, U17, U18: 74HC04; SO-14_3.9x8.65mm_P1.27mm

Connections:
+5V: C1.1, C4.1, C5.1, C7.1, C19.1, C20.1, C21.1, C22.1, J1.4 (+5V), J1.37 (+5V), J2.A4 (VBUS), J2.A9 (VBUS), J2.B4 (VBUS), J2.B9 (VBUS), Q1.3 (S), R3.1, R33.2, U1.4 (R), U1.8 (VCC), U2.14 (VCC), U3.14 (VCC), U12.14 (VCC), U16.14 (VCC), U17.14 (VCC), U18.14 (VCC)
A0: J1.5 (A0), U3.5
A1: J1.6 (A1), U12.1
A2: J1.7 (A2), U12.3
A3: J1.8 (A3), U12.5
A4: J1.9 (A4), U2.1
A5: J1.10 (A5), U2.3
A6: J1.11 (A6), U2.5
A7: J1.12 (A7), U16.1
A8: J1.13 (A8), U16.3
A9: J1.14 (A9), U16.5
A10: J1.15 (A10), U17.1
A11: J1.16 (A11), U17.3
A12: J1.17 (A12), U17.5
A13: J1.18 (A13), U18.1
A14: J1.19 (A14), U18.3
A15: J1.20 (A15), U18.9
ACC/: J1.38 (ACC/), U3.11
BE: J1.31 (BE), U2.11
CLK: J1.39 (CLK), U3.13
D0: J1.21 (D0), U18.5
D1: J1.22 (D1), U18.11
D2: J1.23 (D2), U18.13
D3: J1.24 (D3), U17.9
D4: J1.25 (D4), U17.11
D5: J1.26 (D5), U17.13
D6: J1.27 (D6), U16.9
D7: J1.28 (D7), U16.11
GND: C1.2, C2.1, C3.2, C4.2, C5.2, C6.2, C7.2, C19.2, C20.2, C21.2, C22.2, J1.1 (Vss), J1.40 (Vss), J2.A1 (GND), J2.A12 (GND), J2.B1 (GND), J2.B12 (GND), J2.S1 (SHIELD), Q2.3 (S), R1.2, R2.2, R34.1, SW1.2, U1.1 (GND), U2.7 (GND), U3.7 (GND), U12.7 (GND), U16.7 (GND), U17.7 (GND), U18.7 (GND)
IRQ/: J1.32 (IRQ/), U2.13
NMI/: J1.33 (NMI/), U12.9
unnamed: D1.4 (Green_A), R70.2
unnamed: D1.1 (Green_K), D1.3 (Red_A), U12.2
unnamed: D1.2 (Red_K), R15.2
unnamed: D2.2 (A), D3.1 (K), R3.2, U1.7 (DIS)
unnamed: D2.1 (K), RV1.1
unnamed: D3.2 (A), RV1.3
unnamed: D4.2 (A), U12.12
unnamed: D4.1 (K), R5.2
unnamed: D5.4 (Green_A), R35.2
unnamed: D5.1 (Green_K), D5.3 (Red_A), U2.8
unnamed: D5.2 (Red_K), R36.2
unnamed: D6.2 (A), U3.8
unnamed: D6.1 (K), R7.2
unnamed: D7.2 (A), U3.10
unnamed: D7.1 (K), R10.2
unnamed: D8.2 (A), U3.2
unnamed: D8.1 (K), R9.2
unnamed: D9.4 (Green_A), R18.2
unnamed: D9.1 (Green_K), D9.3 (Red_A), U3.12
unnamed: D9.2 (Red_K), R68.2
unnamed: D10.4 (Green_A), R13.2
unnamed: D10.1 (Green_K), D10.3 (Red_A), U16.2
unnamed: D10.2 (Red_K), R14.2
unnamed: D11.4 (Green_A), R19.2
unnamed: D11.1 (Green_K), D11.3 (Red_A), U2.6
unnamed: D11.2 (Red_K), R20.2
unnamed: D12.2 (A), U3.4
unnamed: D12.1 (K), R11.2
unnamed: D13.4 (Green_A), R81.2
unnamed: D13.1 (Green_K), D13.3 (Red_A), U17.10
unnamed: D13.2 (Red_K), R24.2
unnamed: D14.4 (Green_A), R16.2
unnamed: D14.1 (Green_K), D14.3 (Red_A), U18.12
unnamed: D14.2 (Red_K), R17.2
unnamed: D15.4 (Green_A), R51.2
unnamed: D15.1 (Green_K), D15.3 (Red_A), U17.4
unnamed: D15.2 (Red_K), R52.2
unnamed: D16.4 (Green_A), R39.2
unnamed: D16.1 (Green_K), D16.3 (Red_A), U16.10
unnamed: D16.2 (Red_K), R40.2
unnamed: D17.4 (Green_A), R69.2
unnamed: D17.1 (Green_K), D17.3 (Red_A), U17.12
unnamed: D17.2 (Red_K), R71.2
unnamed: D18.4 (Green_A), R41.2
unnamed: D18.1 (Green_K), D18.3 (Red_A), U16.8
unnamed: D18.2 (Red_K), R42.2
unnamed: D19.2 (A), U2.12
unnamed: D19.1 (K), R6.2
unnamed: D20.2 (A), U12.8
unnamed: D20.1 (K), R8.2
unnamed: D21.4 (Green_A), R45.2
unnamed: D21.1 (Green_K), D21.3 (Red_A), U12.6
unnamed: D21.2 (Red_K), R46.2
unnamed: D22.4 (Green_A), R47.2
unnamed: D22.1 (Green_K), D22.3 (Red_A), U18.6
unnamed: D22.2 (Red_K), R48.2
unnamed: D23.4 (Green_A), R49.2
unnamed: D23.1 (Green_K), D23.3 (Red_A), U12.4
unnamed: D23.2 (Red_K), R50.2
unnamed: D24.4 (Green_A), R37.2
unnamed: D24.1 (Green_K), D24.3 (Red_A), U16.12
unnamed: D24.2 (Red_K), R38.2
unnamed: D25.4 (Green_A), R53.2
unnamed: D25.1 (Green_K), D25.3 (Red_A), U17.2
unnamed: D25.2 (Red_K), R54.2
unnamed: D26.4 (Green_A), R55.2
unnamed: D26.1 (Green_K), D26.3 (Red_A), U16.6
unnamed: D26.2 (Red_K), R56.2
unnamed: D27.4 (Green_A), R25.2
unnamed: D27.1 (Green_K), D27.3 (Red_A), U3.6
unnamed: D27.2 (Red_K), R26.2
unnamed: D28.4 (Green_A), R57.2
unnamed: D28.1 (Green_K), D28.3 (Red_A), U16.4
unnamed: D28.2 (Red_K), R58.2
unnamed: D29.4 (Green_A), R27.2
unnamed: D29.1 (Green_K), D29.3 (Red_A), U2.4
unnamed: D29.2 (Red_K), R28.2
unnamed: D30.4 (Green_A), R29.2
unnamed: D30.1 (Green_K), D30.3 (Red_A), U2.2
unnamed: D30.2 (Red_K), R30.2
unnamed: D31.4 (Green_A), R59.2
unnamed: D31.1 (Green_K), D31.3 (Red_A), U17.8
unnamed: D31.2 (Red_K), R60.2
unnamed: D32.4 (Green_A), R61.2
unnamed: D32.1 (Green_K), D32.3 (Red_A), U18.10
unnamed: D32.2 (Red_K), R62.2
unnamed: D33.4 (Green_A), R63.2
unnamed: D33.1 (Green_K), D33.3 (Red_A), U18.2
unnamed: D33.2 (Red_K), R64.2
unnamed: D34.4 (Green_A), R65.2
unnamed: D34.1 (Green_K), D34.3 (Red_A), U18.8
unnamed: D34.2 (Red_K), R66.2
unnamed: D35.4 (Green_A), R76.2
unnamed: D35.1 (Green_K), D35.3 (Red_A), U18.4
unnamed: D35.2 (Red_K), R67.2
unnamed: D36.4 (Green_A), R77.2
unnamed: D36.1 (Green_K), D36.3 (Red_A), U17.6
unnamed: D36.2 (Red_K), R78.2
unnamed: D37.1 (K), R12.2
unnamed: D73.4 (Green_A), R74.2
unnamed: D73.1 (Green_K), D73.3 (Red_A), U2.10
unnamed: D73.2 (Red_K), R75.2
unnamed: J2.A5 (CC1), R2.1
unnamed: J2.B5 (CC2), R1.1
unnamed: Q1.2 (D), R13.1, R16.1, R18.1, R19.1, R25.1, R27.1, R29.1, R35.1, R37.1, R39.1, R41.1, R45.1, R47.1, R49.1, R51.1, R53.1, R55.1, R57.1, R59.1, R61.1, R63.1, R65.1, R69.1, R70.1, R74.1, R76.1, R77.1, R81.1
unnamed: Q2.2 (D), R5.1, R6.1, R7.1, R8.1, R9.1, R10.1, R11.1, R12.1, R14.1, R15.1, R17.1, R20.1, R24.1, R26.1, R28.1, R30.1, R36.1, R38.1, R40.1, R42.1, R46.1, R48.1, R50.1, R52.1, R54.1, R56.1, R58.1, R60.1, R62.1, R64.1, R66.1, R67.1, R68.1, R71.1, R75.1, R78.1
unnamed: R32.1, U12.10
unnamed: C2.2, U1.5 (CV)
unnamed: R4.1, U1.3 (Q)
unnamed: C3.1, RV1.2, U1.2 (TR), U1.6 (THR)
RAM/: J1.35 (RAM/), U12.13
RES/: C6.1, D37.2 (A), J1.34 (RES/), SW1.1
ROM_PGM/: J1.30 (ROM_PGM/), U2.9
ROM/: J1.36 (ROM/), U3.9
RW/: J1.29 (RW/), U16.13
SW_BUS_LED: Q1.1 (G), R4.2, R33.1, U12.11
SW_BUS_LEDb: Q2.1 (G), R32.2, R34.2
SYNC: J1.2 (SYNC), U3.1
VP/: J1.3 (VP/), U3.3

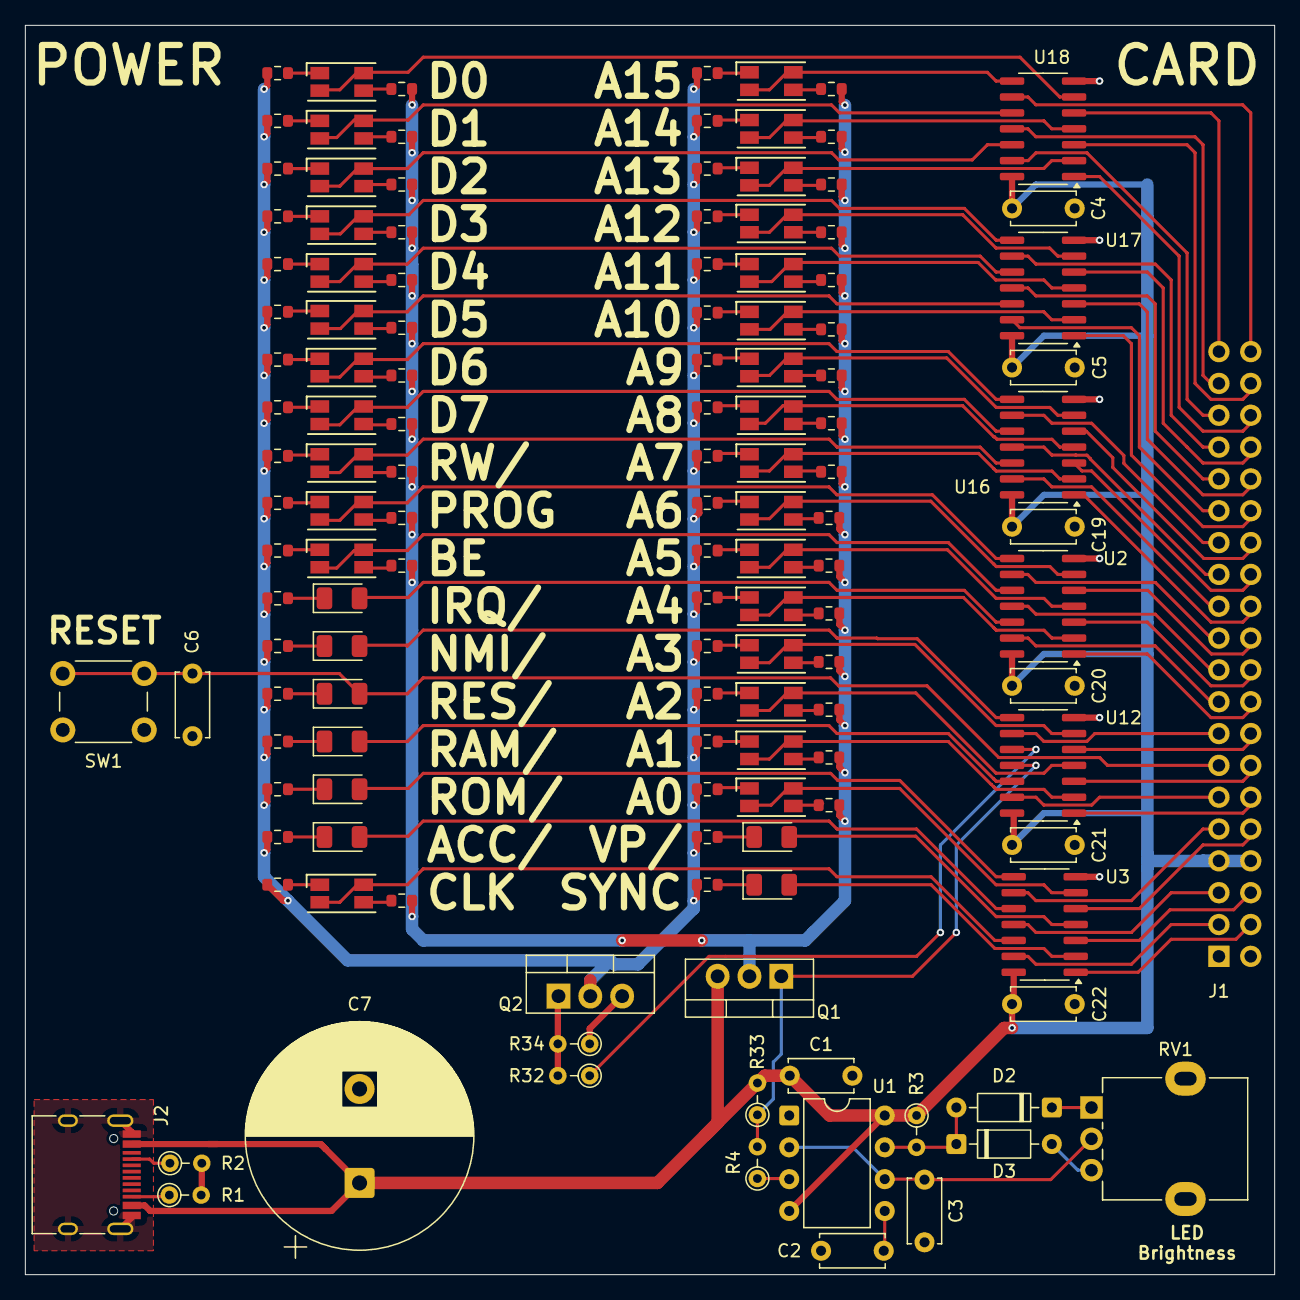
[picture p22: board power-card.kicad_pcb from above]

Board: 2 copper layers, 99.7 x 99.7 mm, 133 parts (0 on the bottom side), 150 nets.

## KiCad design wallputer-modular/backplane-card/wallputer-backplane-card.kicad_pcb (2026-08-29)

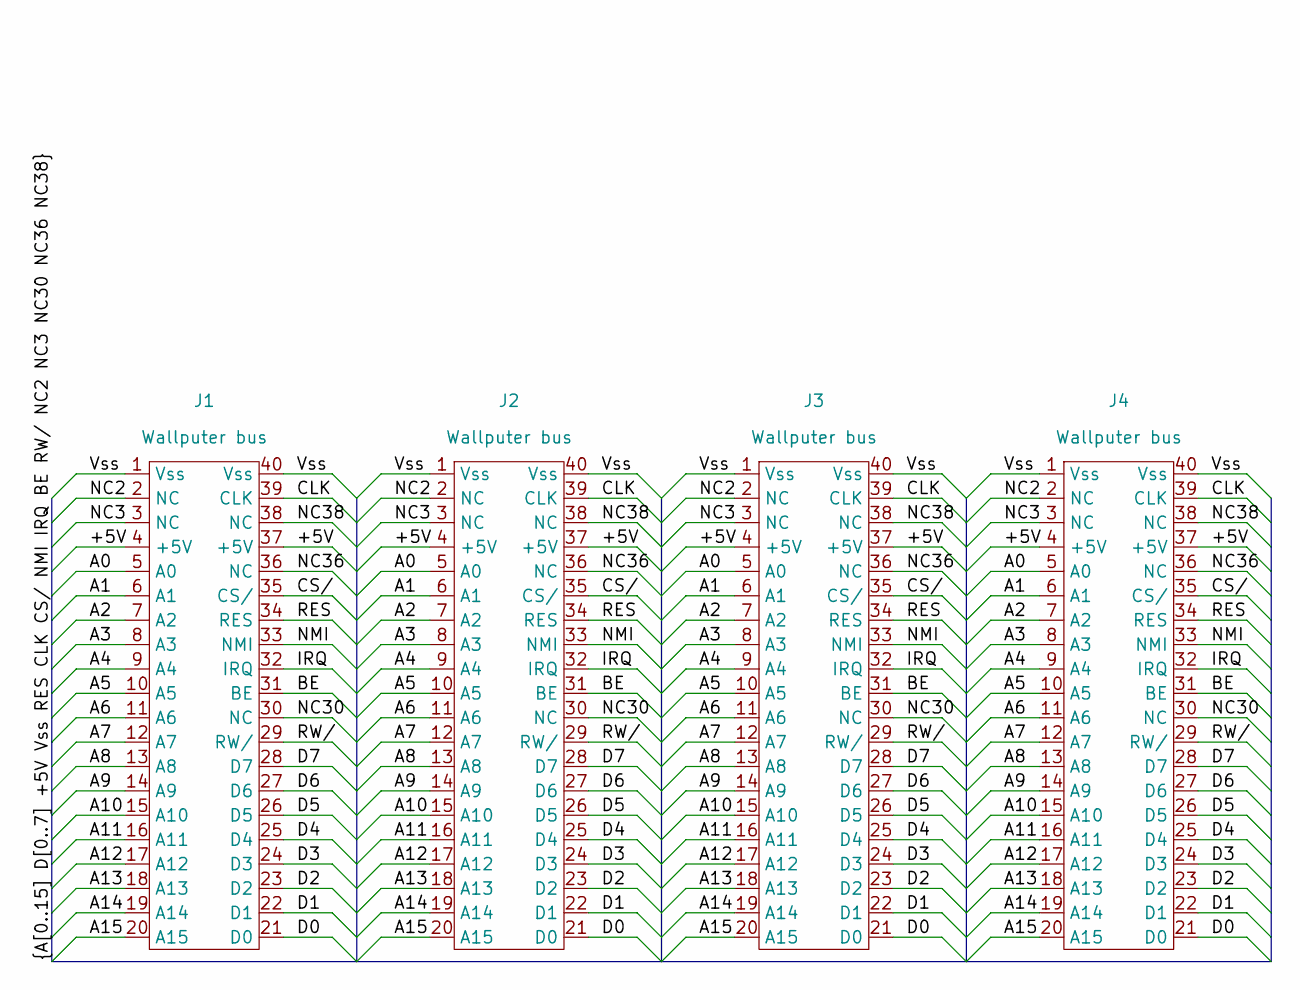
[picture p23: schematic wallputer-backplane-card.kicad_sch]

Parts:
J1: Wallputer_Bus_Header
J2, J3, J4: Wallputer_Bus_Socket

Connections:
/+5V: J1.4 (+5V), J1.37 (+5V), J2.4 (+5V), J2.37 (+5V), J3.4 (+5V), J3.37 (+5V), J4.4 (+5V), J4.37 (+5V)
/A0: J1.5 (A0), J2.5 (A0), J3.5 (A0), J4.5 (A0)
/A1: J1.6 (A1), J2.6 (A1), J3.6 (A1), J4.6 (A1)
/A2: J1.7 (A2), J2.7 (A2), J3.7 (A2), J4.7 (A2)
/A3: J1.8 (A3), J2.8 (A3), J3.8 (A3), J4.8 (A3)
/A4: J1.9 (A4), J2.9 (A4), J3.9 (A4), J4.9 (A4)
/A5: J1.10 (A5), J2.10 (A5), J3.10 (A5), J4.10 (A5)
/A6: J1.11 (A6), J2.11 (A6), J3.11 (A6), J4.11 (A6)
/A7: J1.12 (A7), J2.12 (A7), J3.12 (A7), J4.12 (A7)
/A8: J1.13 (A8), J2.13 (A8), J3.13 (A8), J4.13 (A8)
/A9: J1.14 (A9), J2.14 (A9), J3.14 (A9), J4.14 (A9)
/A10: J1.15 (A10), J2.15 (A10), J3.15 (A10), J4.15 (A10)
/A11: J1.16 (A11), J2.16 (A11), J3.16 (A11), J4.16 (A11)
/A12: J1.17 (A12), J2.17 (A12), J3.17 (A12), J4.17 (A12)
/A13: J1.18 (A13), J2.18 (A13), J3.18 (A13), J4.18 (A13)
/A14: J1.19 (A14), J2.19 (A14), J3.19 (A14), J4.19 (A14)
/A15: J1.20 (A15), J2.20 (A15), J3.20 (A15), J4.20 (A15)
/BE: J1.31 (BE), J2.31 (BE), J3.31 (BE), J4.31 (BE)
/CLK: J1.39 (CLK), J2.39 (CLK), J3.39 (CLK), J4.39 (CLK)
/CS/: J1.35 (CS/), J2.35 (CS/), J3.35 (CS/), J4.35 (CS/)
/D0: J1.21 (D0), J2.21 (D0), J3.21 (D0), J4.21 (D0)
/D1: J1.22 (D1), J2.22 (D1), J3.22 (D1), J4.22 (D1)
/D2: J1.23 (D2), J2.23 (D2), J3.23 (D2), J4.23 (D2)
/D3: J1.24 (D3), J2.24 (D3), J3.24 (D3), J4.24 (D3)
/D4: J1.25 (D4), J2.25 (D4), J3.25 (D4), J4.25 (D4)
/D5: J1.26 (D5), J2.26 (D5), J3.26 (D5), J4.26 (D5)
/D6: J1.27 (D6), J2.27 (D6), J3.27 (D6), J4.27 (D6)
/D7: J1.28 (D7), J2.28 (D7), J3.28 (D7), J4.28 (D7)
/IRQ: J1.32 (IRQ), J2.32 (IRQ), J3.32 (IRQ), J4.32 (IRQ)
/NC2: J1.2 (NC), J2.2 (NC), J3.2 (NC), J4.2 (NC)
/NC3: J1.3 (NC), J2.3 (NC), J3.3 (NC), J4.3 (NC)
/NC30: J1.30 (NC), J2.30 (NC), J3.30 (NC), J4.30 (NC)
/NC36: J1.36 (NC), J2.36 (NC), J3.36 (NC), J4.36 (NC)
/NC38: J1.38 (NC), J2.38 (NC), J3.38 (NC), J4.38 (NC)
/NMI: J1.33 (NMI), J2.33 (NMI), J3.33 (NMI), J4.33 (NMI)
/RES: J1.34 (RES), J2.34 (RES), J3.34 (RES), J4.34 (RES)
/RW/: J1.29 (RW/), J2.29 (RW/), J3.29 (RW/), J4.29 (RW/)
/Vss: J1.1 (Vss), J1.40 (Vss), J2.1 (Vss), J2.40 (Vss), J3.1 (Vss), J3.40 (Vss), J4.1 (Vss), J4.40 (Vss)

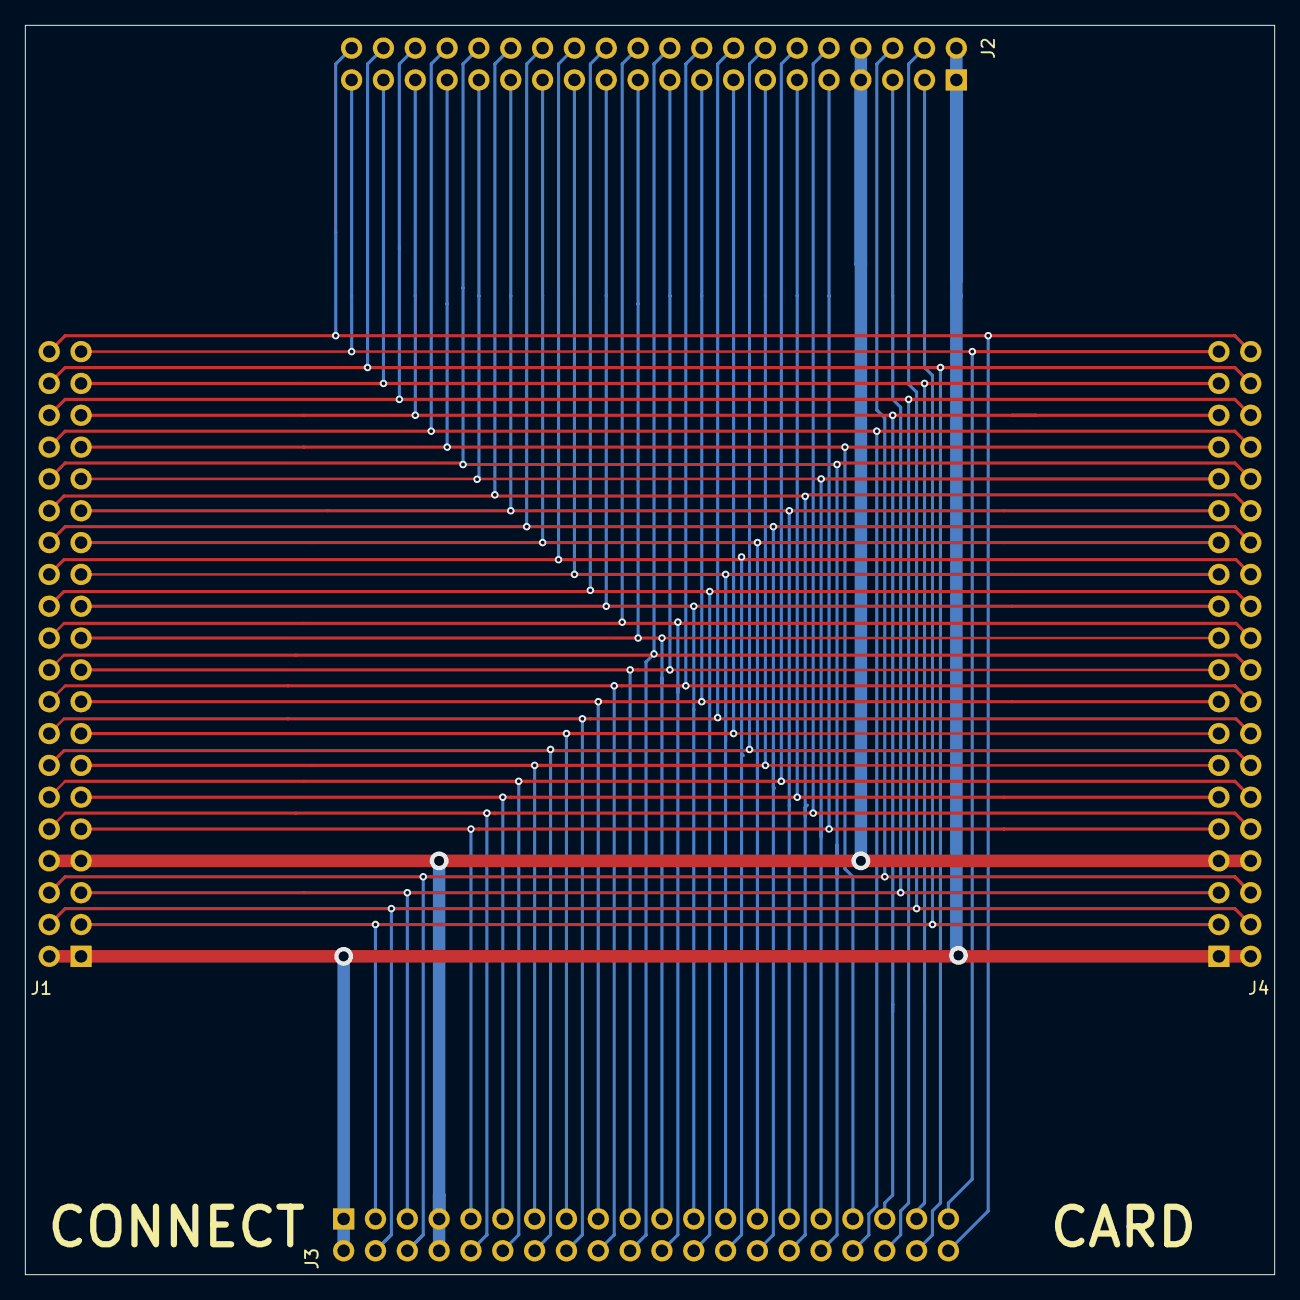
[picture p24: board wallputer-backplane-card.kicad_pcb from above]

Board: 2 copper layers, 99.7 x 99.7 mm, 4 parts (0 on the bottom side), 38 nets.

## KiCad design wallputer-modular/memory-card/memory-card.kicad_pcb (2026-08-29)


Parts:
C1, C2, C3: 100nF; C_Disc_D5.0mm_W2.5mm_P5.00mm
D1, D2: Blue; LED_1206_3216Metric
J1: Wallputer_Bus_Header
Q1, Q2: BSS84; SOT-23
R1: 10k; R_Axial_DIN0204_L3.6mm_D1.6mm_P2.54mm_Vertical
R2, R7: 680; R_0603_1608Metric
R3, R5: 5.1k; R_0603_1608Metric
R4, R6: 100k; R_0603_1608Metric
U1: HM62256BLP; DIP-28_W7.62mm_Socket
U2: 74HC00; DIP-14_W7.62mm_Socket
U3: SST39SF010; DIP-32_W15.24mm_Socket

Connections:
+5V: C1.1, C2.1, C3.1, J1.4 (+5V), J1.37 (+5V), Q1.2 (S), Q2.2 (S), R1.2, R4.2, R6.2, U1.28 (VCC), U2.14 (VCC), U3.32 (VCC)
/A0: J1.5 (A0), U1.10 (A0), U3.12 (A0)
/A1: J1.6 (A1), U1.9 (A1), U3.11 (A1)
/A2: J1.7 (A2), U1.8 (A2), U3.10 (A2)
/A3: J1.8 (A3), U1.7 (A3), U3.9 (A3)
/A4: J1.9 (A4), U1.6 (A4), U3.8 (A4)
/A5: J1.10 (A5), U1.5 (A5), U3.7 (A5)
/A6: J1.11 (A6), U1.4 (A6), U3.6 (A6)
/A7: J1.12 (A7), U1.3 (A7), U3.5 (A7)
/A8: J1.13 (A8), U1.25 (A8), U3.27 (A8)
/A9: J1.14 (A9), U1.24 (A9), U3.26 (A9)
/A10: J1.15 (A10), U1.21 (A10), U3.23 (A10)
/A11: J1.16 (A11), U1.23 (A11), U3.25 (A11)
/A12: J1.17 (A12), U1.2 (A12), U3.4 (A12)
/A13: J1.18 (A13), U1.26 (A13), U3.28 (A13)
/A14: J1.19 (A14), U1.1 (A14), U1.22 (~OE), U2.10, U3.29 (A14)
/A15: J1.20 (A15), U2.4, U2.5, U2.12
/D0: J1.21 (D0), U1.11 (Q0), U3.13 (D0)
/D1: J1.22 (D1), U1.12 (Q1), U3.14 (D1)
/D2: J1.23 (D2), U1.13 (Q2), U3.15 (D2)
/D3: J1.24 (D3), U1.15 (Q3), U3.17 (D3)
/D4: J1.25 (D4), U1.16 (Q4), U3.18 (D4)
/D5: J1.26 (D5), U1.17 (Q5), U3.19 (D5)
/D6: J1.27 (D6), U1.18 (Q6), U3.20 (D6)
/D7: J1.28 (D7), U1.19 (Q7), U3.21 (D7)
ACC/: J1.38 (ACC/), U2.8
CLK: J1.39 (CLK), U2.1
GND: C1.2, C2.2, C3.2, D1.1 (K), D2.1 (K), J1.1 (Vss), J1.40 (Vss), U1.14 (GND), U2.7 (GND), U3.2 (A16), U3.3 (A15), U3.16 (GND)
unnamed: D1.2 (A), R2.1
unnamed: D2.2 (A), R7.1
unnamed: Q1.3 (D), R2.2
unnamed: Q1.1 (G), R3.1, R4.1
unnamed: Q2.3 (D), R7.2
unnamed: Q2.1 (G), R5.1, R6.1
unnamed: U2.11, U3.24 (OE)
RAM/: J1.35 (RAM/), R3.2, U1.20 (~CS), U2.3
ROM_PGM/: J1.30 (NC), R1.1, U3.31 (PGM)
ROM/: J1.36 (ROM/), R5.2, U2.2, U2.6, U2.9, U3.22 (CE)
RW/: J1.29 (RW/), U1.27 (~WE), U2.13

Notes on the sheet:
CE/ and OE/ are split for programming
Memory address selection 0x0000 - 0x3FFF RAM 0x4000 - 0x7FFF Peripherals 0x8000 - 0xFFFF ROM


Board: 2 copper layers, 99.7 x 99.7 mm, 18 parts (0 on the bottom side), 39 nets.

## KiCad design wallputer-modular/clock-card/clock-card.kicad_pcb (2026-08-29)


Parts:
C1, C10: 10uF; CP_Radial_D5.0mm_P2.00mm
C2, C7: 103; C_Disc_D5.0mm_W2.5mm_P5.00mm
C3, C4, C5, C6, C8, C9, C11, C12: 100nF; C_Disc_D5.0mm_W2.5mm_P5.00mm
D1: Red / MHz; LED_D1.8mm_W3.3mm_H2.4mm
D2: Yellow / kHz; LED_D1.8mm_W3.3mm_H2.4mm
D3: Green / Hz; LED_D1.8mm_W3.3mm_H2.4mm
J1: Wallputer_Bus_*
J2: ICP; PinHeader_1x04_P2.54mm_Vertical
Q2, Q4, Q6: BSS84; SOT-23
R1, R3: 1k; R_Axial_DIN0204_L3.6mm_D1.6mm_P2.54mm_Vertical
R2, R4: 10k; R_Axial_DIN0204_L3.6mm_D1.6mm_P2.54mm_Vertical
R5: 1M; R_Axial_DIN0204_L3.6mm_D1.6mm_P2.54mm_Vertical
R6, R7, R9: 1k; R_0603_1608Metric
R8, R11, R14: 100k; R_0603_1608Metric
R10: 68; R_0603_1608Metric
R15, R16, R17, R18, R19, R20, R21, R22: 330; R_0603_1608Metric
RV1: 1M; Potentiometer_Alpha_RD901F-40-00D_Single_Vertical
SW1: switch clock; SW_PUSH_6mm_H4.3mm
SW2: step; SW_PUSH_6mm_H4.3mm
U1: 74HC14; DIP-14_W7.62mm_Socket
U2, U4: NE555P; DIP-8_W7.62mm
U3: 74HC93; DIP-14_W7.62mm_Socket
U5: 74HC153; DIP-16_W7.62mm_Socket
U6: ATtiny1616-S; SOIC-20W_7.5x12.8mm_P1.27mm
U7, U8, U9: INND-TS40
Y1: 1 MHz; Oscillator_DIP-14

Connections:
+5V: C3.2, C5.1, C6.2, C8.1, C9.1, C11.1, J1.4 (+5V), J1.37 (+5V), J2.4, Q2.2 (S), Q4.2 (S), Q6.2 (S), R2.2, R3.2, R5.2, R8.1, R11.1, R14.1, SW2.1, U1.14 (VCC), U2.4 (R), U2.8 (VCC), U3.5 (VCC), U4.4 (R), U4.8 (VCC), U5.16 (VCC), Y1.14 (Vcc)
CLK: J1.39 (CLK), R10.1, U5.7 (Qa)
GND: C1.2, C2.2, C3.1, C4.2, C5.2, C7.1, C8.2, C9.2, C10.2, C11.2, C12.2, D1.1 (K), D2.1 (K), D3.1 (K), J1.1 (Vss), J1.40 (Vss), J2.2, R4.1, SW1.1, U1.5, U1.7 (GND), U1.9, U1.11, U2.1 (GND), U3.10 (GND), U4.1 (GND), U5.1 (~ENa), U5.3 (I3a), U5.8 (GND), U6.20 (GND), Y1.7 (GND)
unnamed: C4.1, R2.1, SW1.2, U1.1
unnamed: C6.1, R4.2, SW2.2, U1.3
unnamed: D1.2 (A), R6.1
unnamed: D2.2 (A), R7.1
unnamed: D3.2 (A), R9.1
unnamed: J2.1, U6.16 (~RESET/PA0)
unnamed: C12.1, J2.3, U6.1 (VCC)
unnamed: Q2.3 (D), U7.6 (CC)
unnamed: Q2.1 (G), R8.2, U6.6 (PB5)
unnamed: Q4.3 (D), U8.6 (CC)
unnamed: Q4.1 (G), R11.2, U6.7 (PB4)
unnamed: Q6.3 (D), U9.6 (CC)
unnamed: Q6.1 (G), R14.2, U6.8 (PB3)
unnamed: R1.2, RV1.2
unnamed: R10.2, U1.13
unnamed: C2.1, U2.5 (CV)
unnamed: R1.1, R3.1, U2.7 (DIS)
unnamed: U2.3 (Q), U5.4 (I2a)
unnamed: C1.1, RV1.3, U2.2 (TR), U2.6 (THR)
unnamed: U3.1 (~CKB), U3.2 (R0(1)), U3.12 (Q0), U5.14 (A)
unnamed: U3.3 (R0(2)), U3.9 (Q1), U5.2 (B)
unnamed: U1.2, U3.14 (~CKA)
unnamed: C7.2, U4.5 (CV)
unnamed: C10.1, R5.1, U4.6 (THR), U4.7 (DIS)
unnamed: U4.3 (Q), U5.5 (I1a)
unnamed: U1.4, U4.2 (TR)
unnamed: U5.6 (I0a), Y1.8 (OUT)
unnamed: R15.1, U6.17 (PA1)
unnamed: R16.1, U6.18 (PA2)
unnamed: R17.1, U6.19 (PA3)
unnamed: R6.2, U6.3 (PA5)
unnamed: R7.2, U6.4 (PA6)
unnamed: R9.2, U6.5 (PA7)
unnamed: R22.1, U6.11 (PB0)
unnamed: U1.12, U6.9 (PB2)
unnamed: R18.1, U6.12 (PC0)
unnamed: R19.1, U6.13 (PC1)
unnamed: R20.1, U6.14 (PC2)
unnamed: R21.1, U6.15 (PC3)
unnamed: R15.2, U7.10 (A), U8.10 (A), U9.10 (A)
unnamed: R16.2, U7.9 (B), U8.9 (B), U9.9 (B)
unnamed: R17.2, U7.8 (C), U8.8 (C), U9.8 (C)
unnamed: R18.2, U7.5 (D), U8.5 (D), U9.5 (D)
unnamed: R22.2, U7.7 (DP), U8.7 (DP), U9.7 (DP)
unnamed: R19.2, U7.1 (E), U8.1 (E), U9.1 (E)
unnamed: R20.2, U7.2 (F), U8.2 (F), U9.2 (F)
unnamed: R21.2, U7.3 (G), U8.3 (G), U9.3 (G)

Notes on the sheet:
Jumper on pins 3 and 4 for normal use. Remove jumper for programming

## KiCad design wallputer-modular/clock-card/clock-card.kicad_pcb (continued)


Board: 2 copper layers, 99.7 x 99.7 mm, 53 parts (0 on the bottom side), 50 nets.

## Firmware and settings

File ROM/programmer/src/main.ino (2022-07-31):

#include "bus.h"
#include "eeprom.h"
#include "bus-monitor.h"
#include "firmware.h"

unsigned long readLongFromSerial(int len);
void readSerialCommand(byte in);

void setup() {
    Serial.begin(115200);
    delay(3);
    Serial.println("Started");

    pinMode(CPU_RW, INPUT);
    pinMode(CPU_CLOCK, INPUT);
    pinMode(CPU_BE, OUTPUT);
}

void loop() {
    if (Serial.available()) {
        readSerialCommand( Serial.read() );
    }
}

void readSerialCommand(byte in)
{
    int firmware_index = 0;
    int progmem_index = 0;
    byte data;
    long address;

    switch(in)  {
        case 'E' : Serial.println("CMD: Erase"); eeprom_setup();eeprom_eraseChip(); Serial.println("Erased"); break;
        case '0' : Serial.println("data 0"); eeprom_setup();setData(0x01); break;
        case '1' : Serial.println("data 1"); eeprom_setup();setData(0x02); break;
        case '2' : Serial.println("data 2"); eeprom_setup();setData(0x04); break;
        case '3' : Serial.println("data 3"); eeprom_setup();setData(0x08); break;
        case '4' : Serial.println("data 4"); eeprom_setup();setData(0x10); break;
        case '5' : Serial.println("data 5"); eeprom_setup();setData(0x20); break;
        case '6' : Serial.println("data 6"); eeprom_setup();setData(0x40); break;
        case '7' : Serial.println("data 7"); eeprom_setup();setData(0x80); break;
        case 'R' : Serial.println("CMD: Read");
            eeprom_setup();
            for(unsigned int i = 0; i < FIRMWARESIZE; i++) {
                if (i%8 == 0) {
                    Serial.println();
                    char addrText[4];
                    sprintf(addrText, "%04X", 0x8000 + i);
                    Serial.print(addrText);
                }
                Serial.print(" ");
                Serial.print(eeprom_readData(0x8000 + i), HEX);
            }
            break;
        case 'W' : Serial.println("CMD: Write");
            eeprom_setup();
            for(unsigned int address = 0; address < FIRMWARESIZE; address++) {
                if (address >0 && address % 32767 == 0) {
                    progmem_index = 0;
                    firmware_index++;
                }

                data = pgm_read_byte_near(&FIRMWARE[firmware_index][progmem_index]);
                eeprom_programData(data, 0x8000 + address);

                if (address % 8 == 0) {
                    Serial.println();
                    char addrText[4];
                    sprintf(addrText, "%04X", 0x8000 + address);
                    Serial.print(addrText);
                }
                Serial.print(" ");
                Serial.print(data, HEX);
                progmem_index++;
            }
            Serial.println("Written");
            break;
        case 'M' : Serial.println("CMD: Monitor ON"); monitor_start(); break;
        case 'm' : Serial.println("CMD: monitor OFF"); monitor_stop(); break;
        case 'r' : Serial.println("CMD: read address: ");
            eeprom_setup();
            address = readLongFromSerial(4);
            Serial.print("got address: ");
            Serial.println(address, HEX);
            Serial.print("data: ");
            Serial.println(eeprom_readData(address), HEX);
//             digitalWrite(CPU_BE, LOW);
//             setAddress(address);
//             delay(1000);
//             Serial.println(getData(), HEX);
//             digitalWrite(CPU_BE, HIGH);
            break;
        case 'w' : Serial.println("CMD: write address: ");
            eeprom_setup();
            address = readLongFromSerial(4);
//             Serial.print("got address: ");
            Serial.println(address, HEX);
            Serial.print("write data: ");
            data = readLongFromSerial(2);

//             digitalWrite(CPU_BE, LOW);
//             eeprom_setCtrlPins();
            Serial.print("writing ");
            Serial.print(data, HEX);
            Serial.print(" to ");
            Serial.println(address, HEX);
            eeprom_programData(data, address);
//             delay(1000);
//             Serial.println("stopping eeprom");
//             eeprom_teardown();
//             delay(1000);
            Serial.println("done");
//             digitalWrite(CPU_BE, HIGH);
            break;
        case 't':
        digitalWrite(EEPROM_OE, HIGH);
        digitalWrite(EEPROM_CE, HIGH);
        digitalWrite(EEPROM_WE,HIGH);

        for(unsigned int i = 0; i < 255; i++) {
        setDataIn();
        Serial.println(i);
            setAddress(i+i*256);
            //setData(i);
            readLongFromSerial(1);
        }

        default : Serial.println("E(rase); R(ead); W(rite); (M)onitor on; (m)onitor off;"); break;
    }
}

unsigned long readLongFromSerial(int len) {
    char buffer[len+3];
    buffer[0] = '0';
    buffer[1] = 'x';
    for (int i=2;i<len+2;i++) {
        while(Serial.available() == 0);
        buffer[i] = Serial.read();
    }
    buffer[len+2] = '\0';
    long result = strtoul(buffer, NULL, 0);
    return result;
}

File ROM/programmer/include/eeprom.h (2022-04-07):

//#include "bus.h"

void eeprom_setCtrlPins();                                   //Setup control signals
void eeprom_unSetCtrlPins();                                 //Setup control signals
void eeprom_setByte(byte out);                               //Set data across D0-D7
byte eeprom_readByte();                                      //Read byte across D0-D7
void eeprom_writeByte(byte data, unsigned long address);     //Write a byte of data at a specific address
void eeprom_programData(byte data, unsigned long address);   //Executes the program command sequence
byte eeprom_readData(unsigned long address);                 //Read data as specific address
void eeprom_eraseChip();                                     //Executes the erase chip command sequece


void eeprom_setup()
{
    eeprom_setCtrlPins();
    setDataIn();
    setAddrOut();
//    digitalWrite(CPU_BE, LOW); // disable bus

}

void eeprom_teardown() {
    eeprom_unSetCtrlPins();
    setDataIn();
    setAddrOut();
//    digitalWrite(CPU_BE, HIGH); // enable bus
}

void eeprom_eraseChip()
{
  setDataOut();

  eeprom_writeByte(0xAA, 0x5555);
  eeprom_writeByte(0x55, 0x2AAA);
  eeprom_writeByte(0x80, 0x5555);
  eeprom_writeByte(0xAA, 0x5555);
  eeprom_writeByte(0x55, 0x2AAA);
  eeprom_writeByte(0x10, 0x5555);

  delay(100);
  setDataIn();
}

byte eeprom_readData(unsigned long address)
{
  byte temp_read;
  setDataIn();

  digitalWrite(EEPROM_WE, HIGH);
  digitalWrite(EEPROM_OE, HIGH);

  setAddress(address);

  digitalWrite(EEPROM_OE, LOW);
  delayMicroseconds(1);

  temp_read = eeprom_readByte();

  digitalWrite(EEPROM_OE, HIGH);

  return temp_read;
}

void eeprom_writeByte(byte data, unsigned long address)
{
//Serial.println();
//Serial.print("WRITING: ");
//Serial.print(data, HEX);
//Serial.print(" TO ");
//Serial.println(address, HEX);
  digitalWrite(EEPROM_OE, HIGH);
  digitalWrite(EEPROM_WE,HIGH);

  setAddress(address);
  eeprom_setByte(data);

  digitalWrite(EEPROM_WE, LOW);
  delayMicroseconds(1);
  digitalWrite(EEPROM_WE, HIGH);
}

void eeprom_programData(byte data, unsigned long address)
{
  setDataOut();

  eeprom_writeByte(0xAA, 0x5555);
  eeprom_writeByte(0x55, 0x2AAA);
  eeprom_writeByte(0xA0, 0x5555);
  eeprom_writeByte(data, address);

  delayMicroseconds(30);
}

byte eeprom_readByte()
{
  byte temp_in = 0;
  for(int i=0; i <= 7; i++) {
    if (digitalRead(DATA_PINS[i])) {
      bitSet(temp_in, i);
    }
  }
  return temp_in;
}

void eeprom_setByte(byte out)
{
  for(int i=0; i <= 7; i++)
    digitalWrite(DATA_PINS[i], bitRead(out, i));
}

void eeprom_setCtrlPins()
{
  pinMode(EEPROM_CE, OUTPUT);
  pinMode(EEPROM_WE, OUTPUT);
  pinMode(EEPROM_OE, OUTPUT);

  digitalWrite(EEPROM_CE, LOW);
  digitalWrite(EEPROM_WE, HIGH);
  digitalWrite(EEPROM_OE, HIGH);
}

void eeprom_unSetCtrlPins()
{
  digitalWrite(EEPROM_CE, HIGH); // to be pulled down by inverter on A15
  digitalWrite(EEPROM_WE, HIGH);
  digitalWrite(EEPROM_OE, HIGH); // to be pulled down by inverter on A15

  pinMode(EEPROM_CE, INPUT);
  pinMode(EEPROM_WE, INPUT);
  pinMode(EEPROM_OE, INPUT);
}

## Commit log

2022-04-04 fixes, issue with firmware vectors
    [bus.h, eeprom.h, main.ino]
2022-04-06 added schema
    [8bit-cpu-address-decoder.kicad_sch]
2022-04-09 fix program loop; new board
    [main.ino]
2022-04-14 add address display kicad
    [8bit-cpu-address-decoder.kicad_pcb, address display.kicad_pcb, address display.kicad_sch]
2022-04-14 add pcb
2022-04-17 refactor repo
    [8bit-cpu-address-decoder.kicad_pcb, 8bit-cpu-address-decoder.kicad_sch, address display.kicad_pcb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]
2022-04-18 finished bus display
    [8bit-cpu-address-decoder.kicad_sch, address display.kicad_pcb, bus display.kicad_pcb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]
2022-04-21 document CPU board idea
2022-07-07 update ROM board; add log
    [rom-board.kicad_pcb, rom-board.kicad_sch]
2022-07-30 fix build; fix 0xFF; add missing kicad
    [CPU.kicad_pcb, CPU.kicad_sch, rom-board.kicad_sch]
2026-07-18 add oscillator, extend memory map
    [CPU.kicad_pcb, CPU.kicad_sch]
2026-07-20 designing wall-puter
    [wallputer.kicad_pcb, wallputer.kicad_sch]
2026-07-20 fix issues
    [wallputer.kicad_sch]
2026-07-21 replace lcd, fix ERC errors
    [wallputer.kicad_sch]
2026-07-22 bus leds
    [wallputer.kicad_sch]
2026-07-22 fix some erc errors
    [wallputer.kicad_sch]
2026-07-22 shuffle around, organise
    [wallputer.kicad_sch]
2026-07-24 Starting on PCB layout
    [wallputer.kicad_pcb, wallputer.kicad_sch]
2026-08-09 more components routed
    [wallputer.kicad_pcb, wallputer.kicad_sch]
2026-08-09 finish 1st placing
    [wallputer.kicad_pcb, wallputer.kicad_sch]
2026-08-09 update todo
    [wallputer.kicad_pcb]
2026-08-11 fix DRC errors
    [wallputer.kicad_pcb]
2026-08-11 fix power class
2026-08-12 fix ERC and DRC problems
    [wallputer.kicad_pcb, wallputer.kicad_sch]
2026-08-12 ground plane + mounting holes
    [wallputer.kicad_pcb, wallputer.kicad_sch]
2026-08-14 finish board
    [wallputer.kicad_pcb, wallputer.kicad_sch]
2026-08-16 creating modular version
    [wallputer-backplane-card.kicad.sch]
2026-08-16 mv files; create stub for power-card
    [power-card.kicad_pcb, power-card.kicad_sch, wallputer-backplane-card.kicad_pcb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]
2026-08-17 implement power module
    [power-card.kicad_sch]
2026-08-17 fix errors
    [power-card.kicad_sch]
2026-08-18 begin wiring pcb
    [power-card.kicad_pcb, power-card.kicad_sch]
2026-08-23 More layout
    [power-card.kicad_pcb, power-card.kicad_sch]
2026-08-23 finish wiring pcb
    [power-card.kicad_pcb, power-card.kicad_sch]
2026-08-25 redesigning traces
    [power-card.kicad_pcb, power-card.kicad_sch]
2026-08-26 more routing
    [power-card.kicad_pcb]
2026-08-26 finish routing
    [power-card.kicad_pcb]
2026-08-26 clean up routing
    [power-card.kicad_pcb]
2026-08-26 fix drc
    [power-card.kicad_pcb]
2026-08-27 replace dual leds with single for some signals
    [power-card.kicad_pcb, power-card.kicad_sch]
2026-08-27 shift connector up
    [power-card.kicad_pcb]
2026-08-27 resize backplane; add base card
    [base-card.kicad_pcb, base-card.kicad_sch, wallputer-backplane-card.kicad_pcb]
2026-08-27 start on memory card
    [acia-card.kicad_pcb, acia-card.kicad_sch, bus-display-card.kicad_pcb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]
2026-08-27 begin wiring memory card
    [memory-card.kicad_pcb, power-card.kicad_pcb, power-card.kicad_sch]
2026-08-27 wire up memory card
    [memory-card.kicad_pcb]
2026-08-27 fix up, add notes
    [memory-card.kicad_pcb]
2026-08-29 add activation indicators
    [memory-card.kicad_pcb, memory-card.kicad_sch]
2026-08-29 shift down a bit, and make it upside down
    [memory-card.kicad_pcb]
2026-08-29 initial design for clock card
    [clock-card.kicad_sch]
2026-08-29 finish design for clock card
    [clock-card.kicad_pcb, clock-card.kicad_sch]
2026-08-29 improve design a little
    [clock-card.kicad_pcb, clock-card.kicad_sch]
2026-08-29 add card name
    [acia-card.kicad_pcb, base-card.kicad_pcb, bus-display-card.kicad_pcb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]
2026-08-29 start on cpu card
    [cpu-card.kicad_sch]
2026-09-02 do cpu card layout; add git hook; fix project settings
    [cpu-card.kicad_pcb, cpu-card.kicad_sch, power-card.kicad_pcb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]
2026-09-02 fix renders
    [cpu-card.kicad_pcb]
2026-09-02 add readmes and gerbers
    [acia-card-B_Cu.gbr, acia-card-B_Mask.gbr, acia-card-B_Paste.gbr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]
2026-09-04 copy parts of single board
    [acia-card-B_Cu.gbr, acia-card-B_Mask.gbr, acia-card-B_Paste.gbr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]
2026-09-04 document bus display
    [acia-card-B_Cu.gbr, acia-card-B_Mask.gbr, acia-card-B_Paste.gbr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]
2026-09-05 bus display PCB
    [acia-card-B_Cu.gbr, acia-card-B_Mask.gbr, acia-card-B_Paste.gbr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]
2026-09-13 implement acia card
    [acia-card-B_Cu.gbr, acia-card-B_Mask.gbr, acia-card-B_Paste.gbr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]
2026-09-13 implement via board
    [acia-card-B_Cu.gbr, acia-card-B_Mask.gbr, acia-card-B_Paste.gbr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]
